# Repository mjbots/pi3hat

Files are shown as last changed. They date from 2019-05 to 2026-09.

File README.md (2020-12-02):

# mjbots pi3hat #

This contains designs, firmware, and client side libraries for the
mjbots pi3hat.  It is a daughterboard for Raspberry Pi (tm) boards and
similar to provide:

* 4x 5Mbps CAN-FD ports
* 1x 125kbps CAN port
* 1kHz IMU with attitude reference

# LICENSE #

All files contained in this repository, unless otherwise noted, are
available under an Apache 2.0 License
https://www.apache.org/licenses/LICENSE-2.0

# Directory Structure #

* hw/ - Eagle schematic
* fw/ - Firmware
* docs/ - Reference documentation
* lib/ - Client side libraries
* tools/ - bazel build configuration

# FAQ #

## How do I get the best timing performance? ##

A: We recommend using the following configuration:
 * `isolcpus` and `sched_setaffinity` used to keep linux from running
   on the processor interfacing with the pi3hat
 * `chrt 99` to run the process at the maximum real time priority
 * `mlockall` to prevent linux from swapping any part of the process

These are demonstrated in the `--realtime` option of `pi3hat_tool`.

## Will this work on a Raspberry Pi 4? ##

A: Despite the name `pi3hat`, yes it works just fine on a Raspberry Pi
4 too.

## Do I need to use the XT 30 input connector? ##

A: Nope.  You can power the Raspberry Pi with through any means.  The
pi3hat internally only uses the 3.3V output from the Raspberry Pi, and
the input connector is just an independent mechanism to power the Pi.

## Will this work on **insert random board here**? ##

A: Maybe?  If it has the same pinout as a Raspberry Pi, can can be
powered through the GPIO header with 5V @ 2.5A then there is a chance.

## Can I use the Raspberry Pi Camera? ##

A: If you install a higher GPIO riser then it is possible.  Samtec
ESW-120-12-G-D works.  You can install one yourself, or contact
info@mjbots.com to get one fitted at the factory.

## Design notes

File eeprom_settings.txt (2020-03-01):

########################################################################
# EEPROM settings text file
#
# Edit this file for your particular board and run through eepmake tool,
# then use eepflash tool to write to attached HAT ID EEPROM 
#
# Tools available:
#  eepmake   Parses EEPROM text file and creates binary .eep file
#  eepdump   Dumps a binary .eep file as human readable text (for debug)
#  eepflash  Write or read .eep binary image to/from HAT EEPROM
#
########################################################################

########################################################################
# Vendor info

# 128 bit UUID. If left at zero eepmake tool will auto-generate
# RFC 4122 compliant UUID
product_uuid 00000000-0000-0000-0000-000000000000

# 16 bit product id
product_id 0x2306

# 16 bit product version
product_ver 0x0001

# ASCII vendor string  (max 255 characters)
vendor "mjbots Robotic Systems"

# ASCII product string (max 255 characters)
product "mjbots quad pi3 hat"

########################################################################
# GPIO bank settings, set to nonzero to change from the default.
# NOTE these setting can only be set per BANK, uncommenting any of
# these will force the bank to use the custom setting.

# drive strength, 0=default, 1-8=2,4,6,8,10,12,14,16mA, 9-15=reserved
gpio_drive 0

# 0=default, 1=slew rate limiting, 2=no slew limiting, 3=reserved
gpio_slew 0

# 0=default, 1=hysteresis disabled, 2=hysteresis enabled, 3=reserved
gpio_hysteresis 0

# If board back-powers Pi via 5V GPIO header pins:
# 0 = board does not back-power
# 1 = board back-powers and can supply the Pi with a minimum of 1.3A
# 2 = board back-powers and can supply the Pi with a minimum of 2A
# 3 = reserved
# If back_power=2 then USB high current mode will be automatically 
# enabled on the Pi
back_power 2

########################################################################
# GPIO pins, uncomment for GPIOs used on board
# Options for FUNCTION: INPUT, OUTPUT, ALT0-ALT5
# Options for PULL: DEFAULT, UP, DOWN, NONE
# NB GPIO0 and GPIO1 are reserved for ID EEPROM so cannot be set

#         GPIO  FUNCTION  PULL
#         ----  --------  ----
#setgpio  2     INPUT     DEFAULT
#setgpio  3     INPUT     DEFAULT
#setgpio  4     INPUT     DEFAULT
#setgpio  5     INPUT     DEFAULT
#setgpio  6     INPUT     DEFAULT
# SPI0 is 7-11 on ALT0
setgpio  7     ALT0     NONE
setgpio  8     ALT0     NONE
setgpio  9     ALT0     NONE
setgpio  10    ALT0     NONE
setgpio  11    ALT0     NONE
#setgpio  12    INPUT     DEFAULT
#setgpio  13    INPUT     DEFAULT
# 14-15 are UART0 on ALT0
setgpio  14    ALT0     NONE
setgpio  15    ALT0     NONE
# SPI1 is 16-21 on ALT4
setgpio  16    ALT4     NONE
setgpio  17    ALT4     NONE
setgpio  18    ALT4     NONE
setgpio  19    ALT4     NONE
setgpio  20    ALT4     NONE
setgpio  21    ALT4     NONE
#setgpio  22    INPUT     DEFAULT
#setgpio  23    INPUT     DEFAULT
#setgpio  24    INPUT     DEFAULT
#setgpio  25    INPUT     DEFAULT
#setgpio  26    INPUT     DEFAULT
#setgpio  27    INPUT     DEFAULT

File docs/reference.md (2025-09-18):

# mjbots pi3 hat #

This is the reference documentation for the mjbots pi3hat r4.5.
What is it?

The mjbots pi3hat is a daughterboard for a Raspberry Pi (tm) 3 or
Raspberry Pi 4 [1], which provides the following:

 * Power input from 8-54V [2], provides 5V for Raspberry Pi
 * 5x independent 5Mbps CAN-FD buses
 * A 1kHz IMU and attitude reference system
 * A spread spectrum nrf24l01 interface

1. The pi3hat is not compatible with the Raspberry Pi 1, 2, or 5.
2. The pi3hat r4.4 and earlier support 8-44V DC input.

# Pinouts #

## J1/J2 ##

XT30-M power input/output.  The chamfered side of the connector is
negative.

## JC1/JC2/JC3/JC4/JC5 ##

These are JST PH-3, 5Mbps CAN-FD connectors.  Each has a physical
termination resistor permanently installed.

* Pin 1: CANH
* Pin 2: CANL
* Pin 3: Ground

# Orientation #

The pi3hat uses a right handed coordinate system.  The raw IMU
accelerations and rotations are measured about the following axes:

* +x - towards the CAN connectors or HDMI connectors on the RPI
* +y - towards the USB ports on the rpi
* +z - up from the rpi towards the pi3hat

Attitude is measured with respect to a coordinate system of:
* +x forward
* +y right
* +z down

That means, in the absence of any configured mounting angle, the
raspberry pi must be inverted to achieve a pitch and roll of 0.

Finally, note that pi3hat is only an "attitude reference system", and
contains no sensors for measuring heading.  Thus the yaw or heading
value will drift over time and the yaw rate will have a non-zero bias
offset.

# Usage with client-side tools #

## tview / moteus_tool ##

First, install the python library:

```
python -m venv --system-site-packages moteus-venv
source moteus-venv/bin/activate

pip3 install moteus moteus-pi3hat
```

Then both `moteus_tool` and `tview` will be aware of the pi3hat, and
will use its port JC1 by default if no fdcanusb is present.

To use other ports, you need to tell the tool which IDs are present on
which port using the `--pi3hat-cfg` command line option.  It has the
following syntax:

```
--pi3hat-cfg 'BUS1=ID1,ID2,ID3;BUS2=ID4,ID5,ID6
```

So, an example where servo ID 1 and 6 are present on port JC1 (bus 1),
and 3 and 7 are present on port JC2 (bus 2), would look like:

```
sudo bash
source moteus-venv/bin/activate

tview --pi3hat-cfg '1=1,6;2=3,7' -t 1,3,6,7
```

The same `--pi3hat-cfg` works for `moteus_tool` as for `tview`.

## Python ##

Simply perform:

```
sudo apt install libraspberrypi-dev

# If not already created
# python -m venv --system-site-packages moteus-venv

source moteus-venv/bin/activate
pip3 install moteus-pi3hat
```

Then use the same API documented at:
https://github.com/mjbots/moteus/tree/main/lib/python with the caveat that all scripts must be executed as root.

Alternately, the pi3hat transport can be constructed directly using:

```
import moteus
import moteus_pi3hat

transport = moteus_pi3hat.Pi3HatRouter(
    servo_bus_map={...},
)
controller = moteus.Controller(id=1, transport=transport)
```

## C++ ##

To use the pi3hat with C++, a library is provided at:
 https://github.com/mjbots/pi3hat/blob/master/lib/cpp/mjbots/pi3hat/pi3hat.h

It consists of a single standalone C++11 header and source file, which
depends upon nothing but the standard library.  The library provides a
blocking interface that allows all the ports and features to be used
in an efficient manner.  Internally, it bypasses the linux kernel
drivers (which requires it to be run as root), and sometimes
busy-waits the CPU, in order to achieve tight timing performance.

There is a sample user of this library, `pi3hat_tool` in the same
directory which provides a simple command line program that exercises
all of its functionality.

## Board level documentation ##

If you wish to use the existing linux kernel SPI drivers, or write a
custom driver, the board theory of operation and SPI register mappings
are described here.

Internally, the board has 3 separate STM32 processors, each attached
to a SPI bus on the Raspberry Pi:

* *Processor 1* The first processor provides the high speed CAN-FD
  interfaces for CAN connectors JC1 and JC2.  It is connected to the
  Raspberry Pi SPI1 bus, CS0.  Those are the following pins on the 40
  pin GPIO header:

  * Pin 35: CIPO (BCM 19)
  * Pin 38: COPI (BCM 20)
  * Pin 40: SCLK (BCM 21)
  * Pin 12: CS   (BCM 18)
  * Pin 37: IRQ  (BCM 26)

* *Processor 2*: This processor provides the CAN-FD interfaces for JC3
  and JC4.  It is connected to the Raspberry Pi SPI1 bus, CS1.  Pins:

  * Pin 35: CIPO (BCM 19)
  * Pin 38: COPI (BCM 20)
  * Pin 40: SCLK (BCM 21)
  * Pin 11: CS   (BCM 17)
  * Pin 29: IRQ  (BCM 5)

* *Processor 3*: This processor provides the low-speed CAN interface,
  the IMU, and the nrf24l01 logic.  It is connected to the Raspberry
  Pi SPI0 bus, CS0.

  * Pin 21: CIPO (BCM 9)
  * Pin 19: COPI (BCM 10)
  * Pin 23: SCLK (BCM 11)
  * Pin 24: CS   (BCM 8)
  * Pin 15: IRQ  (BCM 22)
  * Pin 16: IRQ  (BCM 23)
  * Pin 18: IRQ  (BCM 24)

# Debugging connectors #

## JP6 ##

 * 1: 5V
 * 2: 3.3V
 * 3: Ground

## I2C ##

This connector directly breaks out I2C pins from the Raspberry Pi:

 * 1: 3.3V
 * 2: SDA / RPI Pin 3
 * 3: SCL / RPI Pin 5
 * 4: Ground

## UT ##

This connector directly breaks out UART pins from the Raspberry Pi:

 * 1: TX / RPI 32
 * 2: RX / RPI 33
 * 3: Ground

## JP4 ##

Reserved debugging connector for processor 1.

## JP3 ##

Reserved debugging connector for processor 2

## JP2 ##

Reserved debugging connector for processor 3

# SPI Protocol #

All of the processors use the same basic SPI protocol, with unique
registers for each of the various functions.

Maximum frequency: 10MHz

The following sequence is used for all SPI transactions (write or
read).

1. CS is pulled low
2. A >= 3 us hold time
3. An 8 byte address is written MSB first
4. A >= 3 us hold time
5. One or more bytes can now be read or written.  When reading, 0's
   should be clocked out.  When writing, the return value can be
   ignored.  Each "address" logically consists of sequence of bytes.
6. A >= 3 us hold time
7. CS is pulled high
8. A minimum 3us turnaround time is required before CS can be pulled
   low again.

## CAN Register Mapping ##

These addresses are present on processor 1, 2, and 3.

* *0* Protocol version: A constant byte 0x04
* *1* Interface type: A constant byte 0x01
* *2* Receive status
  * byte 0-5: Size of up to 6 received frames.  0 means no frame is
    available.  This size includes header information, so is the total
    number of bytes that must be read from address 3 to get a complete
    frame.
* *3* Received frame
  * Reading this address consumes exactly one frame from the received
    queue.
  * byte 0: (0x00 means no data)
    * bit 7: which port this was received on 0=JC1/JC3/JC5 1=JC2/JC4
    * bit 6-0: size of payload + 1 (1-65)
  * byte 1-4: CAN ID, MSB first
  * byte 5+: payload
* *4* Transmit frame with 4 byte ID
  * Writing to this address enqueues one CAN frame to be sent.
  * byte 0:
    * bit 7: which port to send on 0=JC1/JC3/JC5 1=JC2/JC4
    * bit 6-0: size of payload
  * byte 1-4: CAN ID, MSB first
  * byte 5+: payload
* *5* Transmit frame with 2 byte ID
  * Writing to this address enqueues one CAN frame to be sent.
  * byte 0:
    * bit 7: which port to send to 0=JC1/JC3/JC5 1=JC2/JC4
    * bit 6-0: size of payload
  * byte 1-2: CAN ID, MSB first
  * byte 3+: payload
* *6* Error status (read only)
  * Port 0 (JC1/JC3/JC5)
    * byte 0
      * bit 7-6 activity
      * bit 5-3 data last error code
      * bit 2-0 last error code
    * byte 1
      * bit 3 protocol exception
      * bit 2 bus_off
      * bit 1 warning status
      * bit 0 error passive
    * byte 2 - rx error count
    * byte 3 - tx error count
    * byte 4 - reset count
    * byte 5 - reserved
  * Port 1 (JC2/JC4)
    * byte 6
      * bit 7-6 activity
      * bit 5-3 data last error code
      * bit 2-0 last error code
    * byte 7
      * bit 3 protocol exception
      * bit 2 bus_off
      * bit 1 warning status
      * bit 0 error passive
    * byte 8 - rx error count
    * byte 9 - tx error count
    * byte 10 - reset count
    * byte 11 - reserved
* *7* Read configuration Port 1 (JC1/JC3/JC5)
  * byte 0-3: int32 standard bitrate
  * byte 4-7: int32 CAN-FD bitrate
  * byte 8: generate CAN-FD frames
  * byte 9: switch bitrates
  * byte 10: enable automatic retransmission
  * byte 11: restricted mode
  * byte 12: bus monitor mode
  * byte 13: std prescaler
  * byte 14: std sync_jump_width
  * byte 15: std time_seg1
  * byte 16: std time_seg2
  * byte 17: std prescaler
  * byte 18: std sync_jump_width
  * byte 19: std time_seg1
  * byte 20: std time_seg2
* *8* Read configuration Port 2 (JC2/JC4)
  * Same as for 7
* *9* Write configuration Port 1 (JC1/JC3/JC5)
  * Same as for 7
* *10* Write configuration Port 2 (JC2/JC4)
  * Same as for 7

## IMU Register Mapping ##

These addresses are present only on processor 3.

* *32* Protocol version: A constant byte 0x20
* *33* Raw IMU data
  * uint16 _present_
  * float _gx dps_
  * float _gy dps_
  * float _gz dps_
  * float _ax mps2_
  * float _ay mps2_
  * float _az mps2_
* *34* Attitude Data
  * uint8 _present_
  * uint8 _reserved_
  * float _w_
  * float _x_
  * float _y_
  * float _z_
  * float _x dps_
  * float _y dps_
  * float _z dps_
  * float _ax mps2_
  * float _ay mps2_
  * float _az mps2_
  * float _bias x dps_
  * float _bias y dps_
  * float _bias z dps_
  * float _uncertainty w_
  * float _uncertainty x_
  * float _uncertainty y_
  * float _uncertainty z_
  * float _uncertainty bias x dps_
  * float _uncertainty bias y dps_
  * float _uncertainty bias z dps_
  * uint32 _error count_
  * uint32 _last error_
* *35* Read configuration
  * float _roll deg_
  * float _pitch deg_
  * float _yaw deg_
  * uint32t _rate Hz_
* *36* Write configuration
  * The same structure as for address 35.

## RF Register Mapping ##

If a nrf24l01 module is attached, the pi3hat implements a spread
spectrum receiver.  This receiver must be configured with the same ID
as the transmitter for communication to take place.

Each "slot" is transmitted independently and repeatedly according to
the given bitmask schedule.  The individual RF frames occur at 50Hz,
and each bit in the bitmask controls whether the data should be sent
in that particular frame.  So 0xaaaaaaaa would result in the data
being sent every other frame.

* *48* Protocol version: A constant byte 0x11
* *49* Read ID
  * byte 0-3: Common RF ID
* *50* Write ID
* *51* Set data for transmission
  * byte 0: Slot number (0-15)
  * byte 1-4: Transmission schedule (little endian)
  * byte 5+: Data
* *52* Read status
  * byte 0-3: uint32 rx slot counter, 2 bits per slot (little endian)
    * each time new data is received from the transmitter, the 2 bit
      counter for that slot is incremented
  * byte 4-7: uint32 age since last lock from tx (little endian)
* *64-79* Read data from remote transmitter
  * byte 0-3: uint32 age in ms (little endian)
  * byte 4: size (0-16)
  * byte 5-20: data

# Flashing new firmware #

To flash new firmware, openocd 0.11.0 or newer is required.  You can find binaries for many platforms at: https://xpack.github.io/openocd/releases/

Flashing can be performed using the `flash.py` script, for instance to flash a newly compiled image:

```
./flash.py
```

Or to flash a specific .elf file

```
./flash.py 20211129-pi3hat-71c002e71ce804959e681dc7043f6fb5d8147cac.elf
```

Each of the three processors needs to be flashed with the same image.

# pi3hat_tool #

Compiled versions of pi3hat_tool can be found in each github release: https://github.com/mjbots/pi3hat/releases

You want the YYYYMMDD-pi3hat_tools-*.bz2, selecting the appropriate
file for your architecture.

pi3hat_tool can be used perform various diagnostic functions,
including reading attitude:

```
pi@realtimepi:~ $  sudo bash

root@raspberrypi:/home/pi# ./pi3hat_tools/pi3hat_tool --read-att
```

Which will then display the current attitude information.

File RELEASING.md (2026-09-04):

# Releasing pi3hat

pi3hat ships three artifacts that move together under a **single
version** and a **single `vX.Y.Z` tag**:

| Artifact | What it is |
|---|---|
| firmware | the flashable STM32G4 image (`pi3_hat.elf` / `.bin`) |
| python | the `moteus_pi3hat` wheels (one per Python version × Pi architecture) |
| cpp | the header/`FetchContent` C++ client source archive |

A single GitHub Release for the tag carries all of them. The version
lives in two files, kept in sync by `utils/release.py`:

| File | Field | Form |
|---|---|---|
| `lib/python/BUILD` | `VERSION="X.Y.Z"` | full PEP 440 (`1.0.0rc1`) |
| `CMakeLists.txt` | `project(... VERSION X.Y.Z)` | `M.m.p` only (no suffix) |

The Python package is published to PyPI, so the version string must be a
normalized [PEP 440](https://peps.python.org/pep-0440/) version
(`1.0.0`, `1.0.0rc1`, `1.0.0b1`, `1.0.0.dev1`) — *not* the semver
spelling `1.0.0-rc.1`. CMake's `project(VERSION)` only accepts `M.m.p`,
so any pre-release suffix is dropped from `CMakeLists.txt` while the full
string is kept for the wheel and the tag.

## Cutting a release

Run the helper from the repo root, then push:

```bash
# patch bump (1.0.0 -> 1.0.1)
utils/release.py patch

# minor / major
utils/release.py minor
utils/release.py major

# start a pre-release cycle (explicit)
utils/release.py 1.1.0rc1

# iterate a pre-release (1.1.0rc1 -> 1.1.0rc2)
utils/release.py rc

# graduate a pre-release to its final release (1.1.0rc2 -> 1.1.0)
utils/release.py patch

# also bump the Rust crate (on its own pre-stable 0.x line)
utils/release.py patch --rust patch
```

The `patch` bump is overloaded: when current is already a pre-release it
strips the suffix instead of incrementing the patch number (matches
npm/cargo conventions). `minor` and `major` always advance `M.m.p`.

The Rust crate (`lib/rust/moteus-pi3hat`) is versioned separately while
it is pre-stable: it stays on its own `0.x` line rather than the unified
`1.x` number, and is bumped — and later published to crates.io — only
when you pass `--rust`. Omit `--rust` and the crate version is left
untouched, so a release that does not change the crate does not
republish it. `--rust` takes the same `major`/`minor`/`patch` bumps or
an explicit semver version (e.g. `--rust 0.2.0`). When the crate is
declared stable, bump it onto the unified number once with `--rust <that
version>` and pass `--rust` on every release thereafter.

The script:

1. Reads the current version from `lib/python/BUILD`.
2. Computes the new version (or accepts an explicit one) and validates it
   is normalized PEP 440.
3. Writes the new version to `lib/python/BUILD` and `CMakeLists.txt`
   (and, with `--rust`, the crate version to `lib/rust/Cargo.toml`).
4. Commits (if a file changed) and creates the annotated tag `vX.Y.Z`.
5. Prints the `git push` commands.

Before any of that it checks that `CHANGELOG.md` has a `## X.Y.Z`
section with entries for the new version and refuses to tag otherwise
-- rename `## Unreleased` first.  (Entries themselves are added with
the change that introduces them, not at release time.)

Inspect the diff and tag before pushing.

```bash
git push origin HEAD
git push origin v1.0.1
```

You can also kick off a release from the GitHub UI via the
[`Release`](.github/workflows/release.yml) workflow — it runs the same
script in CI, useful when releasing from somewhere without your local
toolchain.

## What the build produces

Pushing the tag fires
[`build-release.yml`](.github/workflows/build-release.yml), which builds
on `ubuntu-24.04` and attaches all of the following to one **draft**
GitHub Release:

- **Firmware**: `pi3hat-fw-<version>+g<sha>.elf` and `.bin`, built with
  `tools/bazel build --cpu stm32g4 -c opt //:target`. The `+g<sha>`
  portion is semver build metadata (the 10-char git short SHA of the
  tagged commit), ignored for version precedence.
- **Python**: for each Python version (3.7, 3.9–3.13) × Pi architecture
  (`armv7l`, `aarch64`), it cross-compiles `//:pi3hat_tools` and attaches
  both:
  - `moteus_pi3hat-<version>-cp<py>-<abi>-<plat>.whl` — the wheel that
    goes to PyPI.
  - `pi3hat_tools-<version>-cp<py>-<arch>.tar.bz2` — the full tool
    bundle (the `pi3hat_tool` binary, the wheel, and the C++ examples +
    sources).
- **C++**: `pi3hat-cpp-<version>.tar.gz`, a source archive of the
  `FetchContent` C++ client (`CMakeLists.txt`, `LICENSE`,
  `lib/cpp/mjbots/pi3hat`, `lib/cpp/examples`). The C++ client is
  normally consumed via `FetchContent` pointing at the `vX.Y.Z` tag;
  this archive is just a convenience download.

The build refuses to run if the pushed tag's version disagrees with
`VERSION` in `lib/python/BUILD` (the wheel filenames are derived from
that file). `utils/release.py` keeps them in sync, so this only trips on
a hand-made tag.

Drafts are not visible to users browsing the Releases page or to `pip`
consumers — they exist only on the maintainer's view of the page.

## Promoting a draft release to public

After the build workflow finishes, validate the draft locally:

1. Go to the repo's Releases page → the draft shows under "Draft" at the
   top. Download the attached artifacts.
2. Flash the firmware on representative hardware; `pip install` a wheel
   into a fresh venv on a Pi and exercise `moteus_tool`/`pi3hat_tool`.
3. When satisfied, publish — click "Publish release" in the UI, or:

   ```bash
   gh release edit v1.0.0 --draft=false
   ```

If something is wrong, abort instead of publishing:

```bash
gh release delete v1.0.0 --yes
git push --delete origin v1.0.0
git tag -d v1.0.0
# ...fix the issue, then re-tag
```

**Promoting the draft is what triggers the PyPI publish.**
[`publish-python-pypi.yml`](.github/workflows/publish-python-pypi.yml)
listens for the `release: published` event, downloads the `*.whl` assets,
and uploads them to PyPI via OIDC. Do not publish a draft until you
intend the wheels to land on PyPI — PyPI is append-only, you cannot
un-publish (only yank).

A pre-release version (anything PEP 440 considers pre-release, e.g.
`1.0.0rc1`) goes to PyPI but `pip install moteus_pi3hat` won't pick it up
unless the user passes `--pre`. So pre-releases are safe to publish.

## Publishing to PyPI — one-time setup

PyPI publishing uses
[trusted publishing](https://docs.pypi.org/trusted-publishers/) via OIDC,
so no API token is stored in this repo.

1. Sign in to PyPI as a maintainer of the `moteus_pi3hat` project.
2. Project settings → Publishing → Add a new pending publisher (or
   trusted publisher if the project already exists). Configure:
   - Owner: `mjbots`
   - Repository name: `pi3hat`
   - Workflow name: `publish-python-pypi.yml`
   - Environment name: `pypi`
3. In this GitHub repo: Settings → Environments → New environment named
   `pypi`. The environment exists so PyPI's trusted-publishing config has
   something to bind to; no required reviewers are needed because the
   "Publish release" action on the draft is the gate.

## Publishing to crates.io — one-time setup

The Rust crate publishes the same way, via crates.io
[trusted publishing](https://crates.io/docs/trusted-publishing) over
OIDC, so no token is stored in the repo.

crates.io trusted publishing is configured under an existing crate's
settings, so the crate must exist first. For the initial `0.x` publish,
run `cargo publish` once manually with a personal API token to create
the crate; then:

1. Sign in to crates.io as an owner of the `moteus-pi3hat` crate.
2. Crate settings → Trusted Publishing → Add a GitHub publisher:
   - Owner: `mjbots`
   - Repository name: `pi3hat`
   - Workflow filename: `publish-rust-crates.yml`
   - Environment name: `crates-io`
3. In this GitHub repo: Settings → Environments → New environment named
   `crates-io` (same role as `pypi`).

Prefer a stored token instead of OIDC? Drop the auth step in
`publish-rust-crates.yml` and add a `CARGO_REGISTRY_TOKEN` secret to the
`crates-io` environment.

## What each workflow does

- [`release.yml`](.github/workflows/release.yml) — manual
  `workflow_dispatch` to bump the version and tag from CI.
- [`build-release.yml`](.github/workflows/build-release.yml) — fires on a
  `v*` tag. Builds the firmware, the cross-compiled Python wheels + tool
  bundles, and the C++ source archive, and attaches them all to one draft
  Release.
- [`publish-python-pypi.yml`](.github/workflows/publish-python-pypi.yml)
  — fires when a `v*` Release is promoted out of draft. Downloads the
  attached wheels and uploads them to PyPI via OIDC trusted publishing.
- [`publish-rust-crates.yml`](.github/workflows/publish-rust-crates.yml)
  — fires when a `v*` Release is promoted out of draft. Builds the
  tagged `moteus-pi3hat` crate and publishes it to crates.io via OIDC
  trusted publishing, skipping if that version is already published.
- [`ci.yml`](.github/workflows/ci.yml) — runs `travis-ci.sh` on every
  push and pull request.

## Local builds

`make_release.py` still builds the same artifacts locally into an output
directory (naming them by date + git hash rather than by version). It is
handy for ad-hoc builds, but the tag-driven `build-release.yml` is the
canonical release path.

## Rust dependency lockfiles

`lib/rust` carries two committed lockfiles: `Cargo.lock` (cargo's own)
and `Cargo.bazel.lock` (the rules_rust crate_universe resolution built
from it). After changing any dependency specification (a crate's
`Cargo.toml`, or the crate list in `WORKSPACE`), regenerate both:

```bash
cd lib/rust && cargo update --workspace   # refreshes Cargo.lock minimally
CARGO_BAZEL_REPIN=1 ./tools/bazel sync --only=crate_index
```

A stale `Cargo.bazel.lock` fails the bazel build with a message that
names `CARGO_BAZEL_REPIN`, so drift is caught rather than silent.

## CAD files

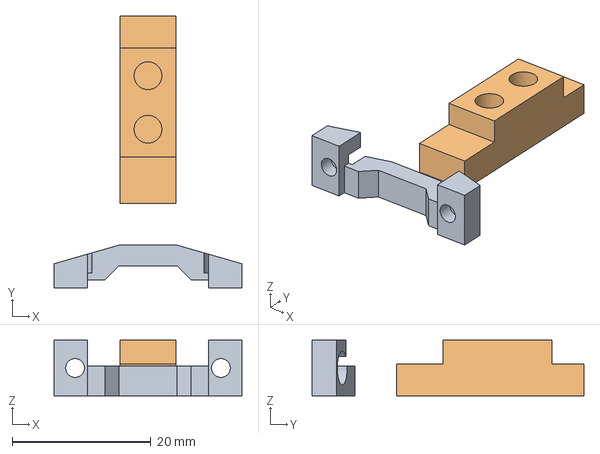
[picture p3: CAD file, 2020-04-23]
3dprint/pi3hat_20200422/rf_clamp.3mf
27.0 x 39.2 x 8.00 mm
rf_clamp.stl
rf_support.stl

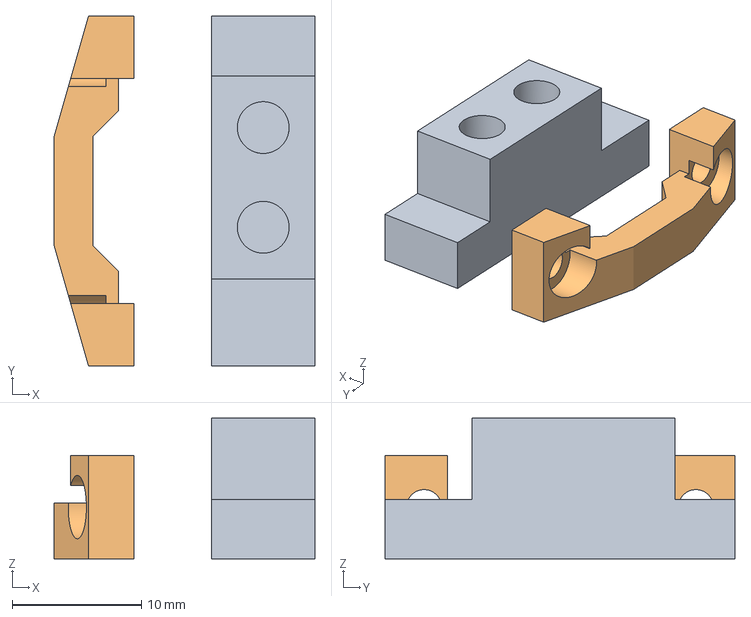
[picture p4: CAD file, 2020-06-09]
3dprint/pi3hat_20200423/rf_support_and_clamp.3mf
20.2 x 27.0 x 10.9 mm
rf_support.stl
rf_clamp.stl

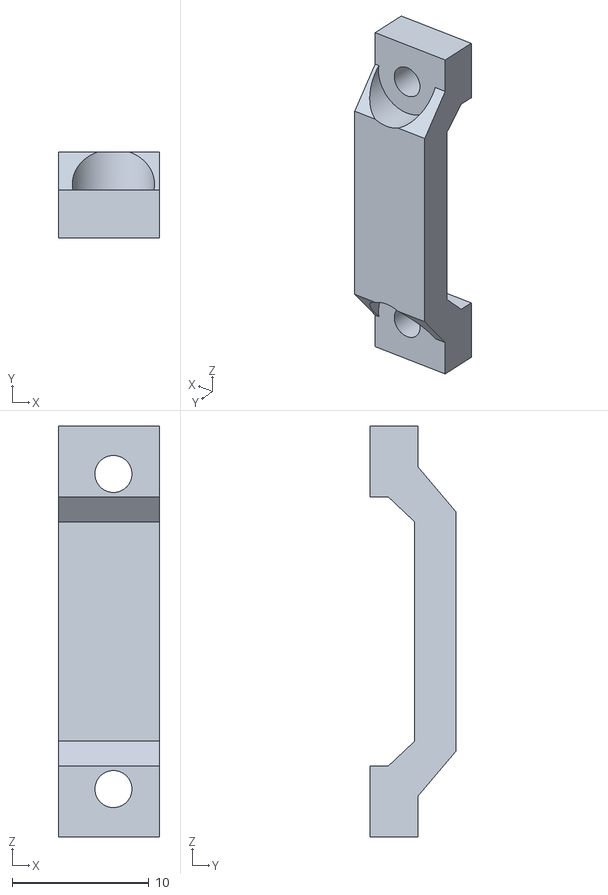
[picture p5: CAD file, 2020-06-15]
3dprint/pi3hat_20200614/rf_clamp.stl
7.35 x 6.25 x 30.0

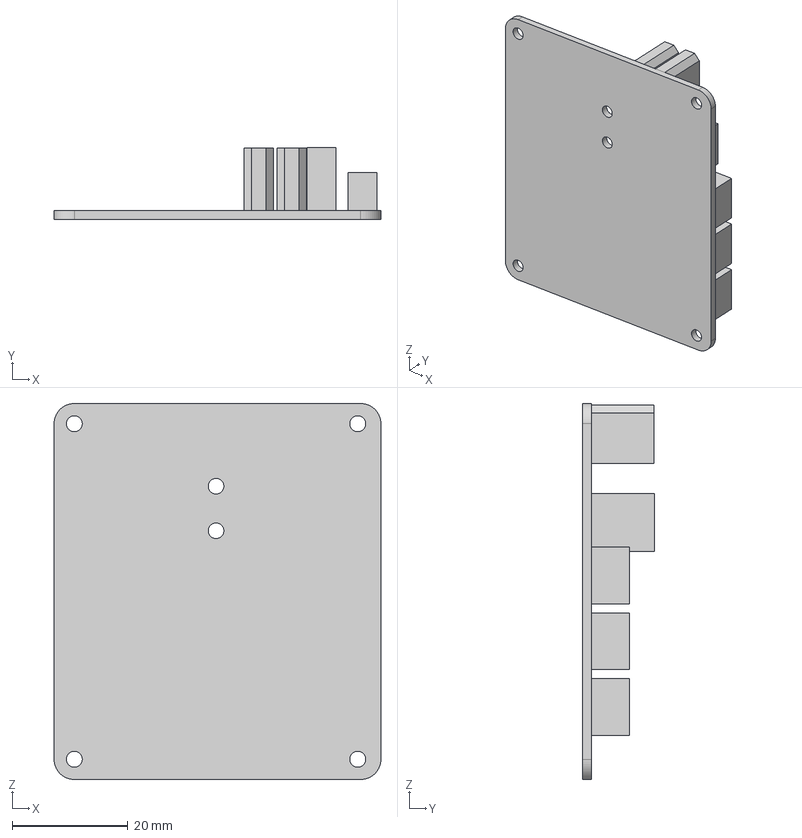
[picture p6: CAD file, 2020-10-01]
hw/r4.1/pi3hat_r4_1.step
56.5 x 12.4 x 65.0 mm

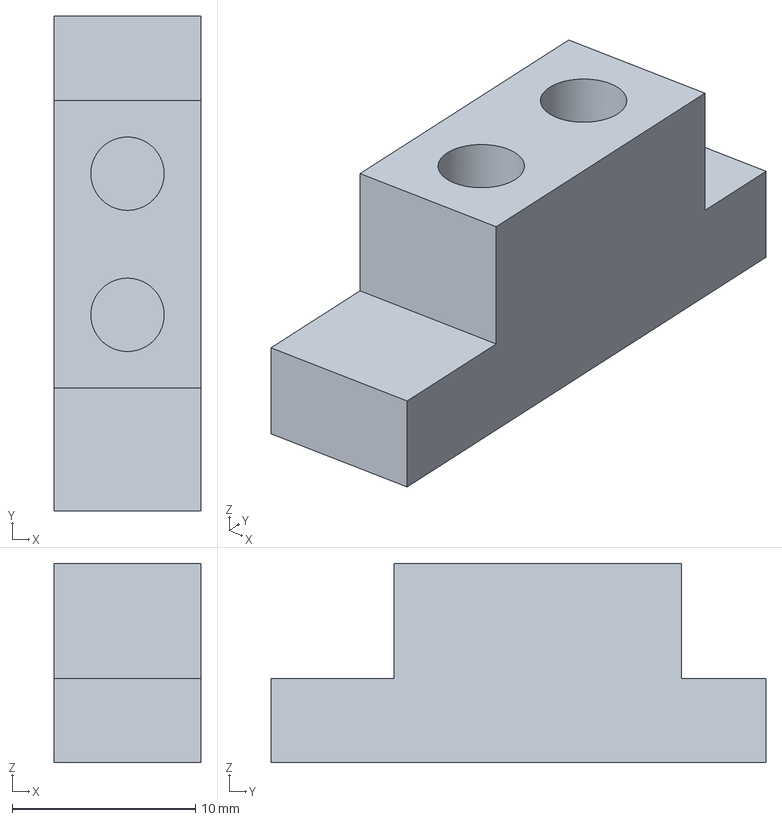
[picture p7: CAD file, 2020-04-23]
3dprint/pi3hat_20200423/rf_support.3mf
8.00 x 27.0 x 10.9 mm

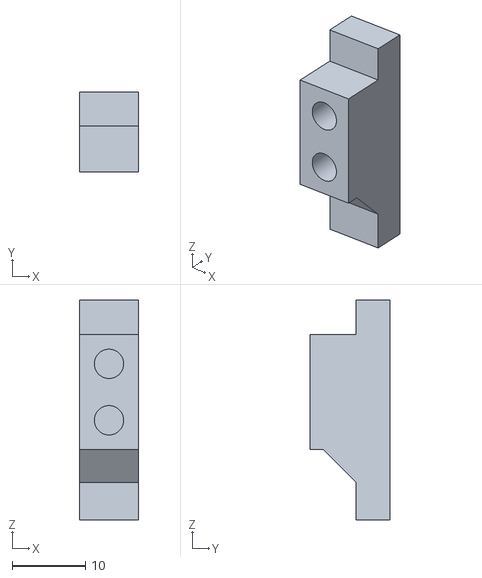
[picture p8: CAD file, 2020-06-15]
3dprint/pi3hat_20200614/rf_support.stl
8.00 x 10.9 x 30.0

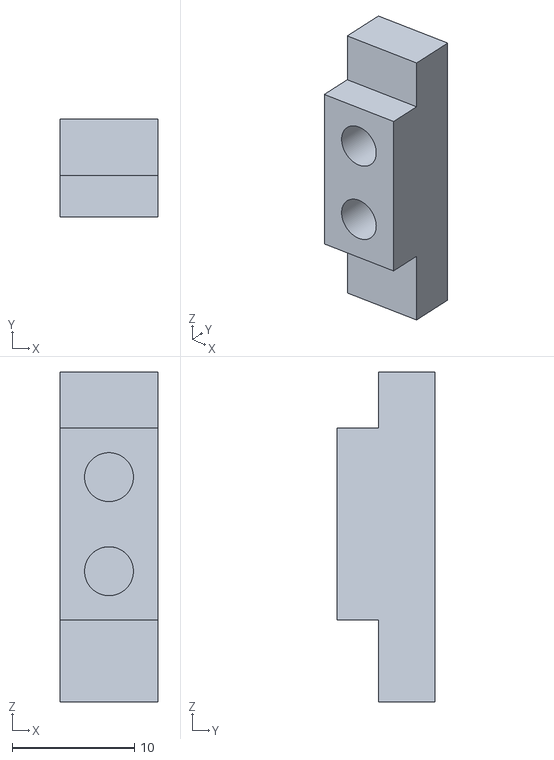
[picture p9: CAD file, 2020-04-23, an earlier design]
3dprint/pi3hat_20200422/rf_support.stl
8.00 x 8.00 x 27.0

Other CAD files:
3dprint/pi3hat_20200422/rf_clamp.stl
3dprint/pi3hat_20200423/rf_support.stl

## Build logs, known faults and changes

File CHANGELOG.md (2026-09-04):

# Changelog

pi3hat ships firmware, the `moteus_pi3hat` Python client, and the C++
client together under a single version; see [RELEASING.md](RELEASING.md)
for the process.

The format is loosely based on [Keep a Changelog](https://keepachangelog.com/).

Entries are added under `## Unreleased` by the change that introduces
them; cutting a release only renames that heading to the version and
date.

## Unreleased

- New Rust client library and moteus transport, `moteus-pi3hat`
  (`lib/rust`), a direct translation of the C++ library. It is
  published to crates.io from the release workflow on its own `0.x`
  version line (`utils/release.py --rust`); the first release is
  0.1.0.
- The tools bundle also ships the Rust examples under `examples/rust/`
- `--pi3hat-cpu` (C++ and Rust) now defaults to the highest isolated
  CPU when the system has any (`isolcpus`), pinning the SPI worker
  there at realtime priority; previously the worker stayed unpinned
  unless a CPU was given. Pass `-1` to never pin.
- C++: `--pi3hat-cfg` rejects out-of-range buses and a servo id mapped
  to more than one bus instead of silently misrouting.
- C++: guard against malformed short CAN frames in `ReadCanFrames`
- C++: fix a race on `Pi3HatMoteusTransport` construction where the
  worker thread could start before its members were constructed
  (intermittent segfault).
- C++: document that `CanConfiguration::restricted_mode` is ignored.
- Documentation: the JC1-4 high speed vs JC5 low speed distinction
  only applied to boards older than r4.5; modern boards make none.
- CI also compiles the Rust crate in its published configuration
  (crates.io `moteus`, locked) and on its declared MSRV (1.75).

## 1.0.0

- First unified semver release. Firmware, the `moteus_pi3hat` Python
  package, and the C++ client now share one version and one `vX.Y.Z` tag.
- Release engineering: tag-driven GitHub Actions build all three
  artifacts into a single Release; promoting the Release publishes the
  Python wheels to PyPI via OIDC trusted publishing.
- The Python package now depends on `moteus>=1.0.0rc1`.

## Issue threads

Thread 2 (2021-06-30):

Max input voltage

Sherdycoder, 2021-06-30:
Reference.md states that the pihat accepts power input from 8-34V, but the product description states 8-44V.

jpieper, 2021-06-30:
Fixed in https://github.com/mjbots/pi3hat/commit/252493835b6ae4a8fa95bc4b884819cf9e681f73

(those specs were for an older version)

Closed 2021-06-30.

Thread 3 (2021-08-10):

moteus_tool auto-detection does not work well on the pi3hat

jpieper, 2021-08-10:
It almost always reports target 1 as available, and then wedges, requiring a power cycle.

Observed in 2021-08-10

jpieper, 2021-08-10:
Resolved in https://github.com/mjbots/moteus/commit/fa707be362e85571b9e7efd7258763730c8dcef3

Closed 2021-08-10.

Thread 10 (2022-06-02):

pi3hat communication is unreliable with 64 bit Raspberry Pi OS

jpieper, 2022-06-02:
Observed by @stephane-caron

When a 64 Raspberry Pi OS is used, flashing moteus controllers over the pi3hat's CAN-FD ports often fails.

jpieper, 2022-06-16:
I've narrowed down the problem to BusyWaitUs not waiting long enough on the 64 bit Pi OS, which can result in the address setup time being violated.  I'm guessing the time resolution is worse, so that subsequent polls can show a larger jump than actually occurred.

I'll have to do some research to see if there is any finer source of timing available.

jpieper, 2022-06-16:
Resolved in d4755d7e01b29cb16e875d17da1546233ea8b6ae and released on pypi as 0.3.21

Closed 2022-06-16.

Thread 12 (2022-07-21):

pi3hat-tool Missing from Pip

MiNdLiKeAsPoOn, 2022-07-21:
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

jpieper, 2022-07-21:
`moteus-pi3hat` can only be installed on a Raspberry Pi running Raspberry Pi OS and some versions of Ubuntu.

`pi3hat_tool` is also not in the pip package, but is available in the separate "tools" package, which is available on the github release page.  It also only runs on the Rasbperry Pi on Linux.

MiNdLiKeAsPoOn, 2022-07-21:
Understood. Thanks and apologies for the mistake

Closed 2022-07-21.

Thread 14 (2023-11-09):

Some issues regarding communication with PI3hat boards

MaxKingWealth, 2023-11-09:
**Hi author, I am trying to use orangepi or upboard to communicate with pi3hat, after installing moteus-pi3hat, my sample code is as follows,**
import asyncio
import math
import moteus
import moteus_pi3hat
import time

async def main():
    transport = moteus_pi3hat.Pi3HatRouter(
        servo_bus_map={
            1:[11]
            },
    )
    controller = moteus.Controller(id=1, transport=transport)

**and after running it, the following error occurs， I would like to ask if there is something wrong with my operation？**

sudo python demo.py
Traceback (most recent call last):
  File "/home/orangepi/Desktop/pi3hat/demo.py", line 96, in <module>
    asyncio.run(main())
  File "/usr/lib/python3.10/asyncio/runners.py", line 44, in run
    return loop.run_until_complete(main)
  File "/usr/lib/python3.10/asyncio/base_events.py", line 646, in run_until_complete
    return future.result()
  File "/home/orangepi/Desktop/pi3hat/demo.py", line 11, in main
    transport = moteus_pi3hat.Pi3HatRouter(
  File "/usr/local/lib/python3.10/dist-packages/moteus_pi3hat/pi3hat_router.py", line 108, in __init__
    self._impl = _pi3hat_router.Pi3HatRouter(options)
RuntimeError: Error setting realtime scheduler, try running as root (use sudo)

jpieper, 2023-11-09:
The pi3hat is only compatible with Raspberry Pi 3 and 4, and not with the orange pi or any up boards.

Closed 2023-11-09.

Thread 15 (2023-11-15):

Hello, may I ask how I can communicate with pi3hat through SPI? Could you please provide an example?

MaxKingWealth, 2023-11-15:
Hello, may I ask how I can communicate with pi3hat through SPI? Could you please provide an example?

jpieper, 2023-11-15:
The SPI communication registers are documented, but using them directly with anything other than the pi3hat c++ or python library is not supported.

You can read the SPI registers through the C++ library using pi3hat_tool like so:

```
sudo ./pi3hat_tool --read-spi 2,32,6
```

To read 6 bytes from address 32 on bus 2.

MaxKingWealth, 2023-11-15:
I don't have raspberry pie on my end, can't I communicate with PI3hat?

jpieper, 2023-11-15:
You can, but it is not supported.  You will have to read the schematic to understand the RPI pinout and follow the reference manual's instructions for which SPI register contains what data.

MaxKingWealth, 2023-11-15:
OK，Thanks a lot, I will try to do it

Closed 2023-11-15.

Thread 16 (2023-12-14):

Add support for Python 3.11 to pi3hat_tool

JGSuw, 2023-12-14:
I would like to add support for Python 3.11 in building pi3hat_tool. Recently, Python 3.11 headers were added to mjbots/bazel_deps, but this added capability is not currently reflected in the build files for pi3hat. This support would be desirable, since currently python3.11 is the only version that is available for Raspian OS and raspberry pi 4. Older versions, such as 3.7, 3.9, and 3.10, must be built from source, which is time consuming.

I have a local branch that has implemented these changes. The changes are modest, and involves small changes to the following files:

- update the commit hash and checksum of the mjbots/bazel_deps github_archive in [pi3hat/tools/workspace/bazel_deps/repository.bzl](https://github.com/mjbots/pi3hat/blob/master/tools/workspace/bazel_deps/repository.bzl) to [806ba633](https://github.com/mjbots/bazel_deps/commit/80b6a3324b6abb5b630f05a8523730c55218860d)
- udpate multiple config_setting in [pi3hat/BUILD](https://github.com/mjbots/pi3hat/blob/master/BUILD)
- add string '3.11' to pyver in [pi3hat/make_release.py](https://github.com/mjbots/pi3hat/blob/c3563cefe31c66d06e2f5e4faa7c2d31ea34eb14/make_release.py#L57)
- add cc_library pybind11_311 to [pi3hat/tools/workspace/pybind11/package.BUILD](https://github.com/mjbots/pi3hat/blob/master/tools/workspace/pybind11/package.BUILD)
- update PYTHON_SHORT_VERSIONS, ABITAG, PTAG, and bdist_wheel filgroup in [pi3hat/lib/python/BUILD](https://github.com/mjbots/pi3hat/blob/master/lib/python/BUILD)
- update cc_binary _pi3hat_router.so in [pi3hat/lib/python/moteus_pi3hat/BUILD](https://github.com/mjbots/pi3hat/blob/master/lib/python/moteus_pi3hat/BUILD)

I may be missing a few small changes here, but I would like to open a pull request with the permission of @jpieper to review the necessary changes.

jpieper, 2023-12-14:
No need to ask permission, just open!  I may not take it directly, but will certainly use it for guidance.

thestumbler, 2023-12-14:
A couple of years ago I was doing a Python project on the Raspberry Pi whose package took a significant amount of time to build. I discovered `piwheels`, infuriatingly spelled with an S unlike its desktop PC counterpart `wheel`. Don't know if that is of any help to you or not.

JGSuw, 2023-12-14:
@thestumbler not sure if that would help, I'm fairly new to distribution of python packages and OSS in general. I will fork this repo, create new branch with changes, and open a pull request after confirming that all the targets build successfully.

The main thing I need to enable my own use case is that the pi3hat_tools wheel gets built for python 3.11, so that I may install it on my pi4.

Closed 2023-12-14.

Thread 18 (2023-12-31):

no pi3hat detected

BJSingh, 2023-12-31:
When I tried to run sample code even as root user getting error hat not detected. But HAT (r4.4) is attached on Raspberry Pi 4 Model B Rev 1.5

root@raspberrypi:/home/pidemo/pi3hat/lib/python/examples# python3 raw_can_example.py
Traceback (most recent call last):
  File "/home/pidemo/pi3hat/lib/python/examples/raw_can_example.py", line 92, in <module>
    asyncio.run(main())
  File "/usr/lib/python3.9/asyncio/runners.py", line 44, in run
    return loop.run_until_complete(main)
  File "/usr/lib/python3.9/asyncio/base_events.py", line 642, in run_until_complete
    return future.result()
  File "/home/pidemo/pi3hat/lib/python/examples/raw_can_example.py", line 39, in main
    transport = moteus_pi3hat.Pi3HatRouter(can=can_config)
  File "/usr/local/lib/python3.9/dist-packages/moteus_pi3hat/pi3hat_router.py", line 108, in __init__
    self._impl = _pi3hat_router.Pi3HatRouter(options)
RuntimeError: No pi3hat detected

jpieper, 2023-12-31:
We resolved this in the mjbots Discord as likely being a problem with the Raspberry Pi used as a host.

Closed 2023-12-31.

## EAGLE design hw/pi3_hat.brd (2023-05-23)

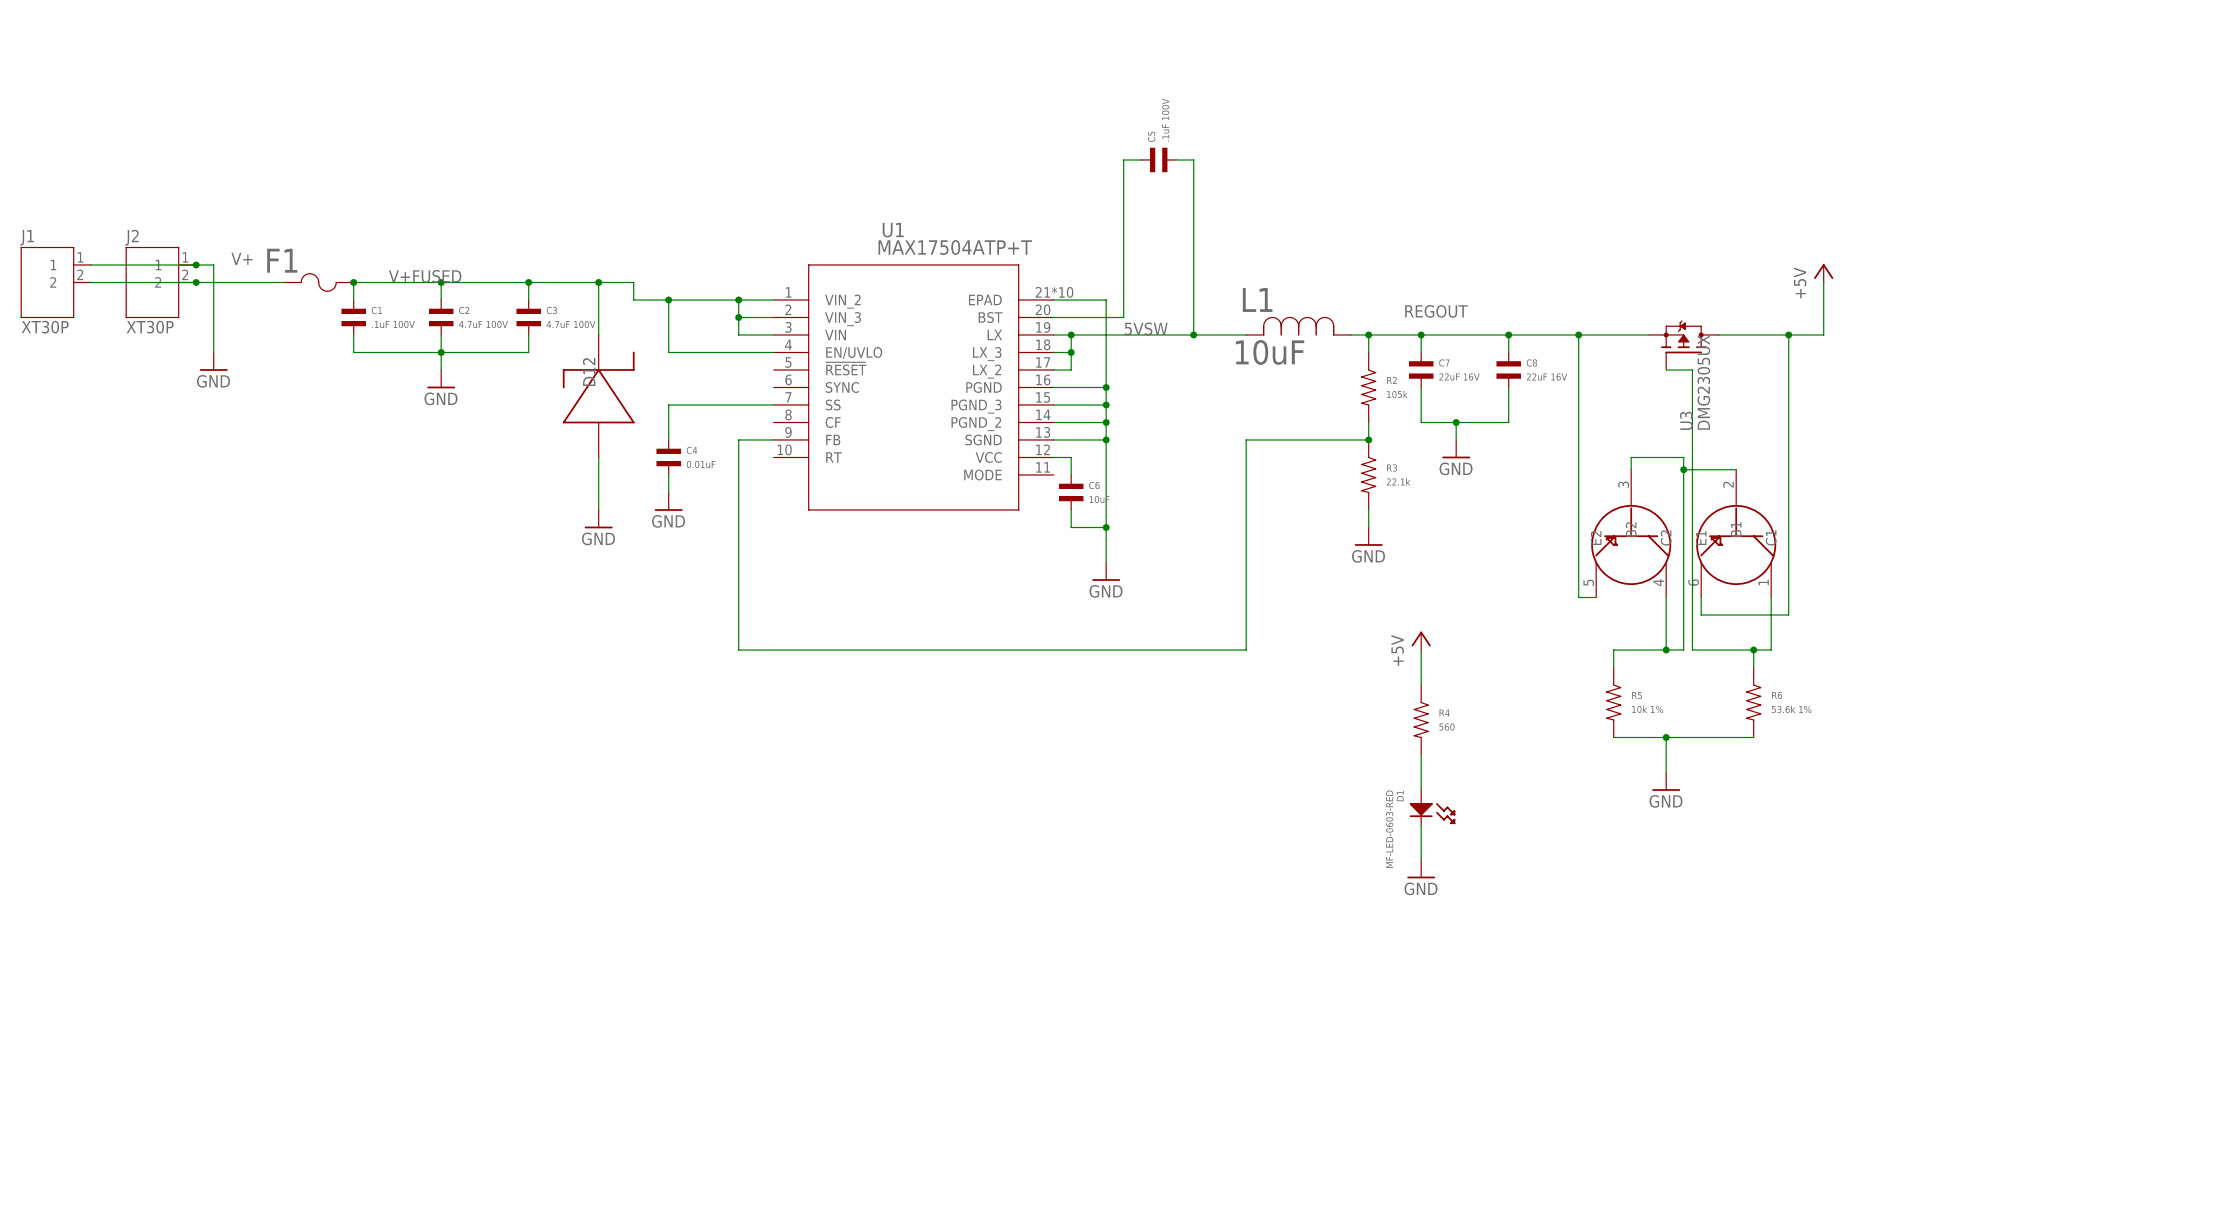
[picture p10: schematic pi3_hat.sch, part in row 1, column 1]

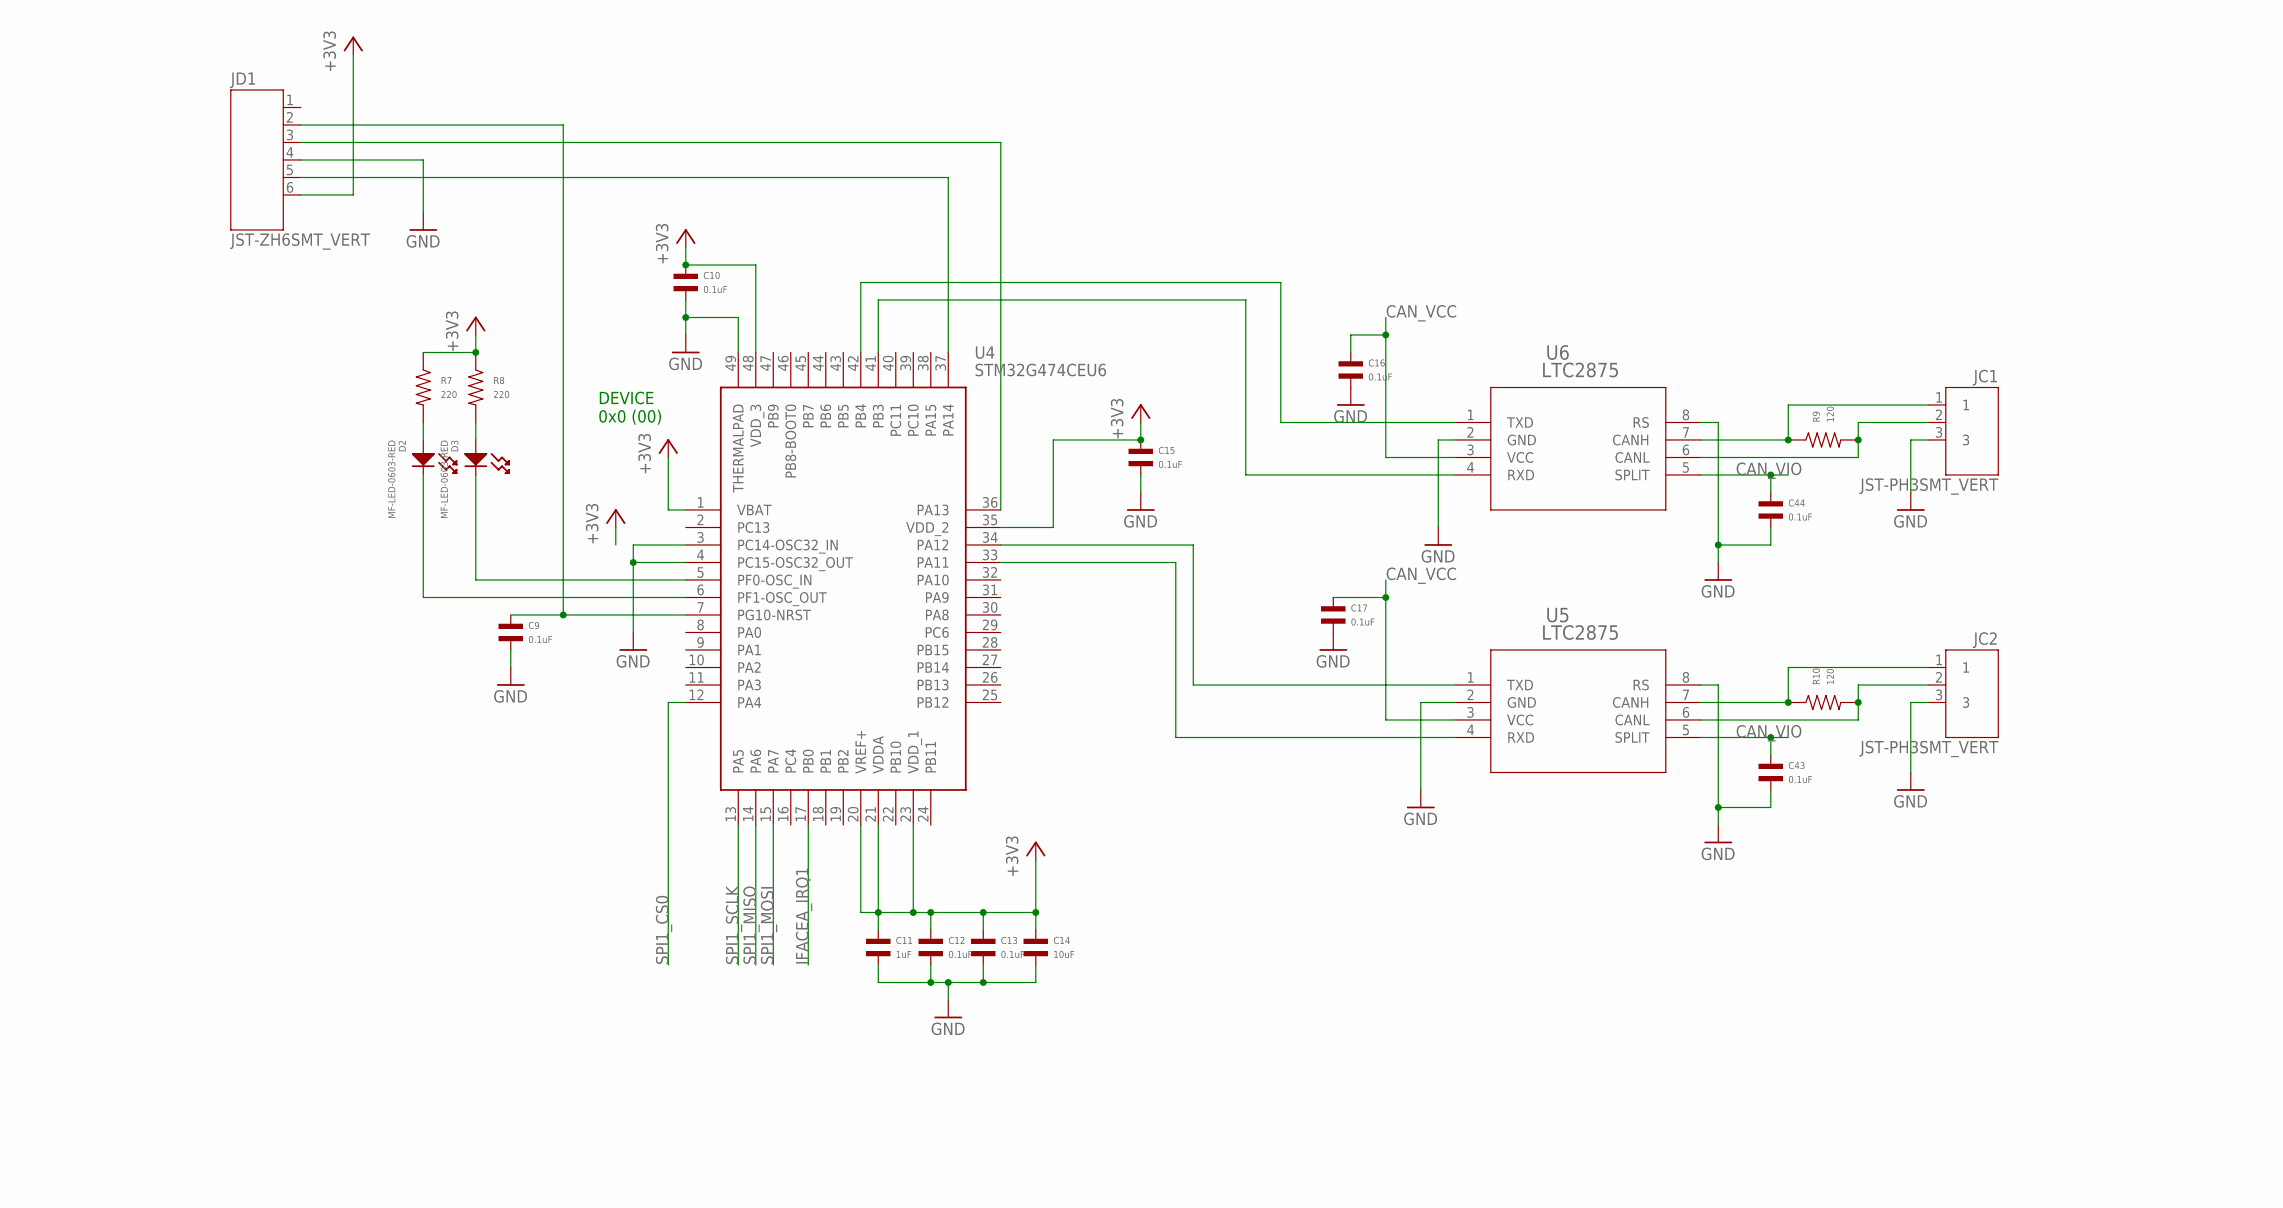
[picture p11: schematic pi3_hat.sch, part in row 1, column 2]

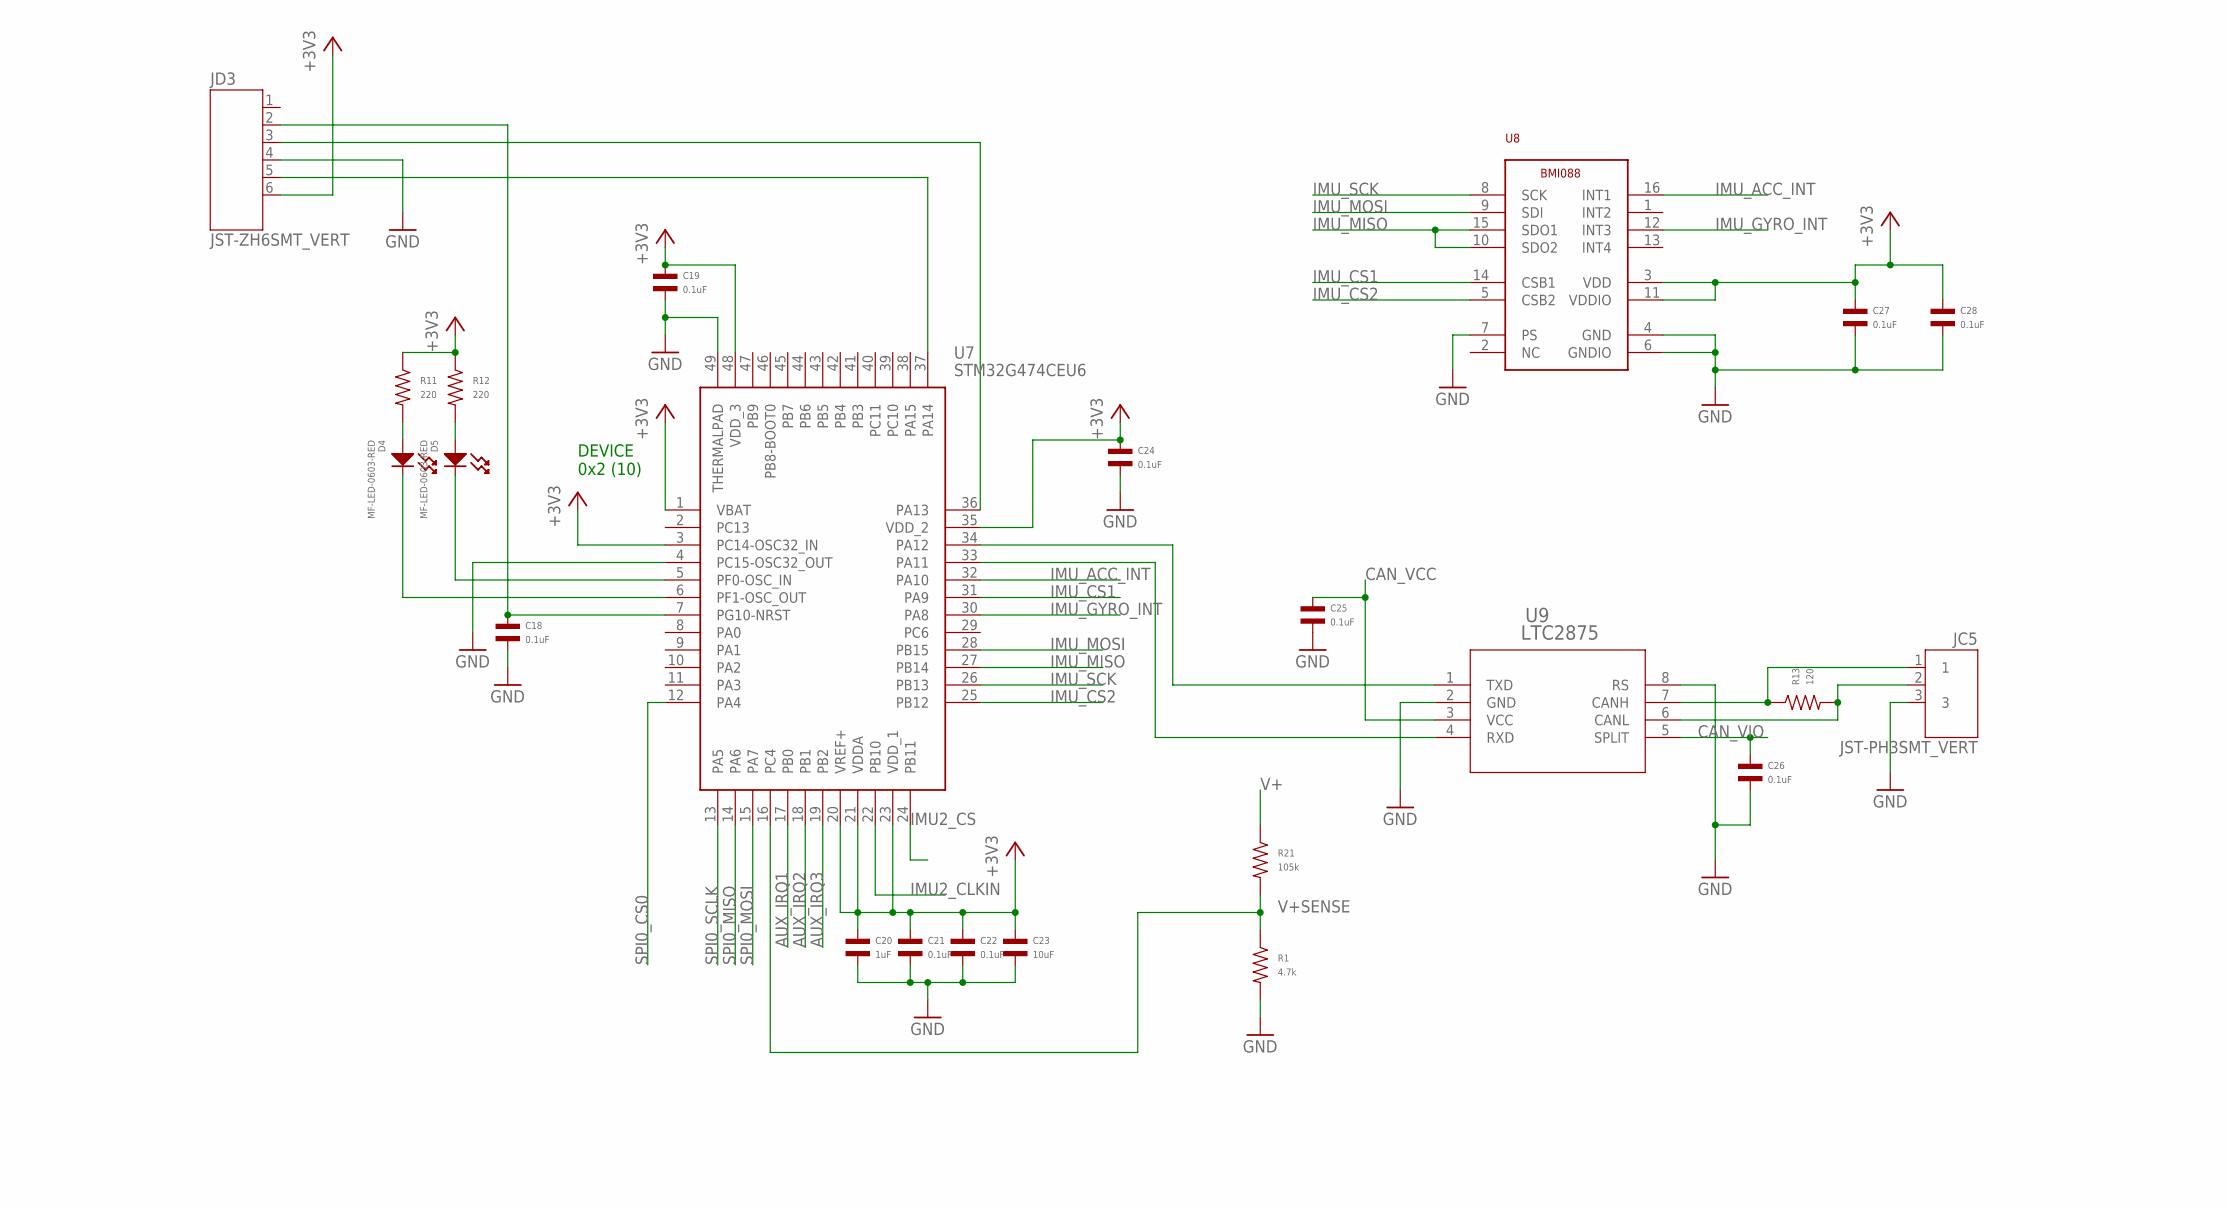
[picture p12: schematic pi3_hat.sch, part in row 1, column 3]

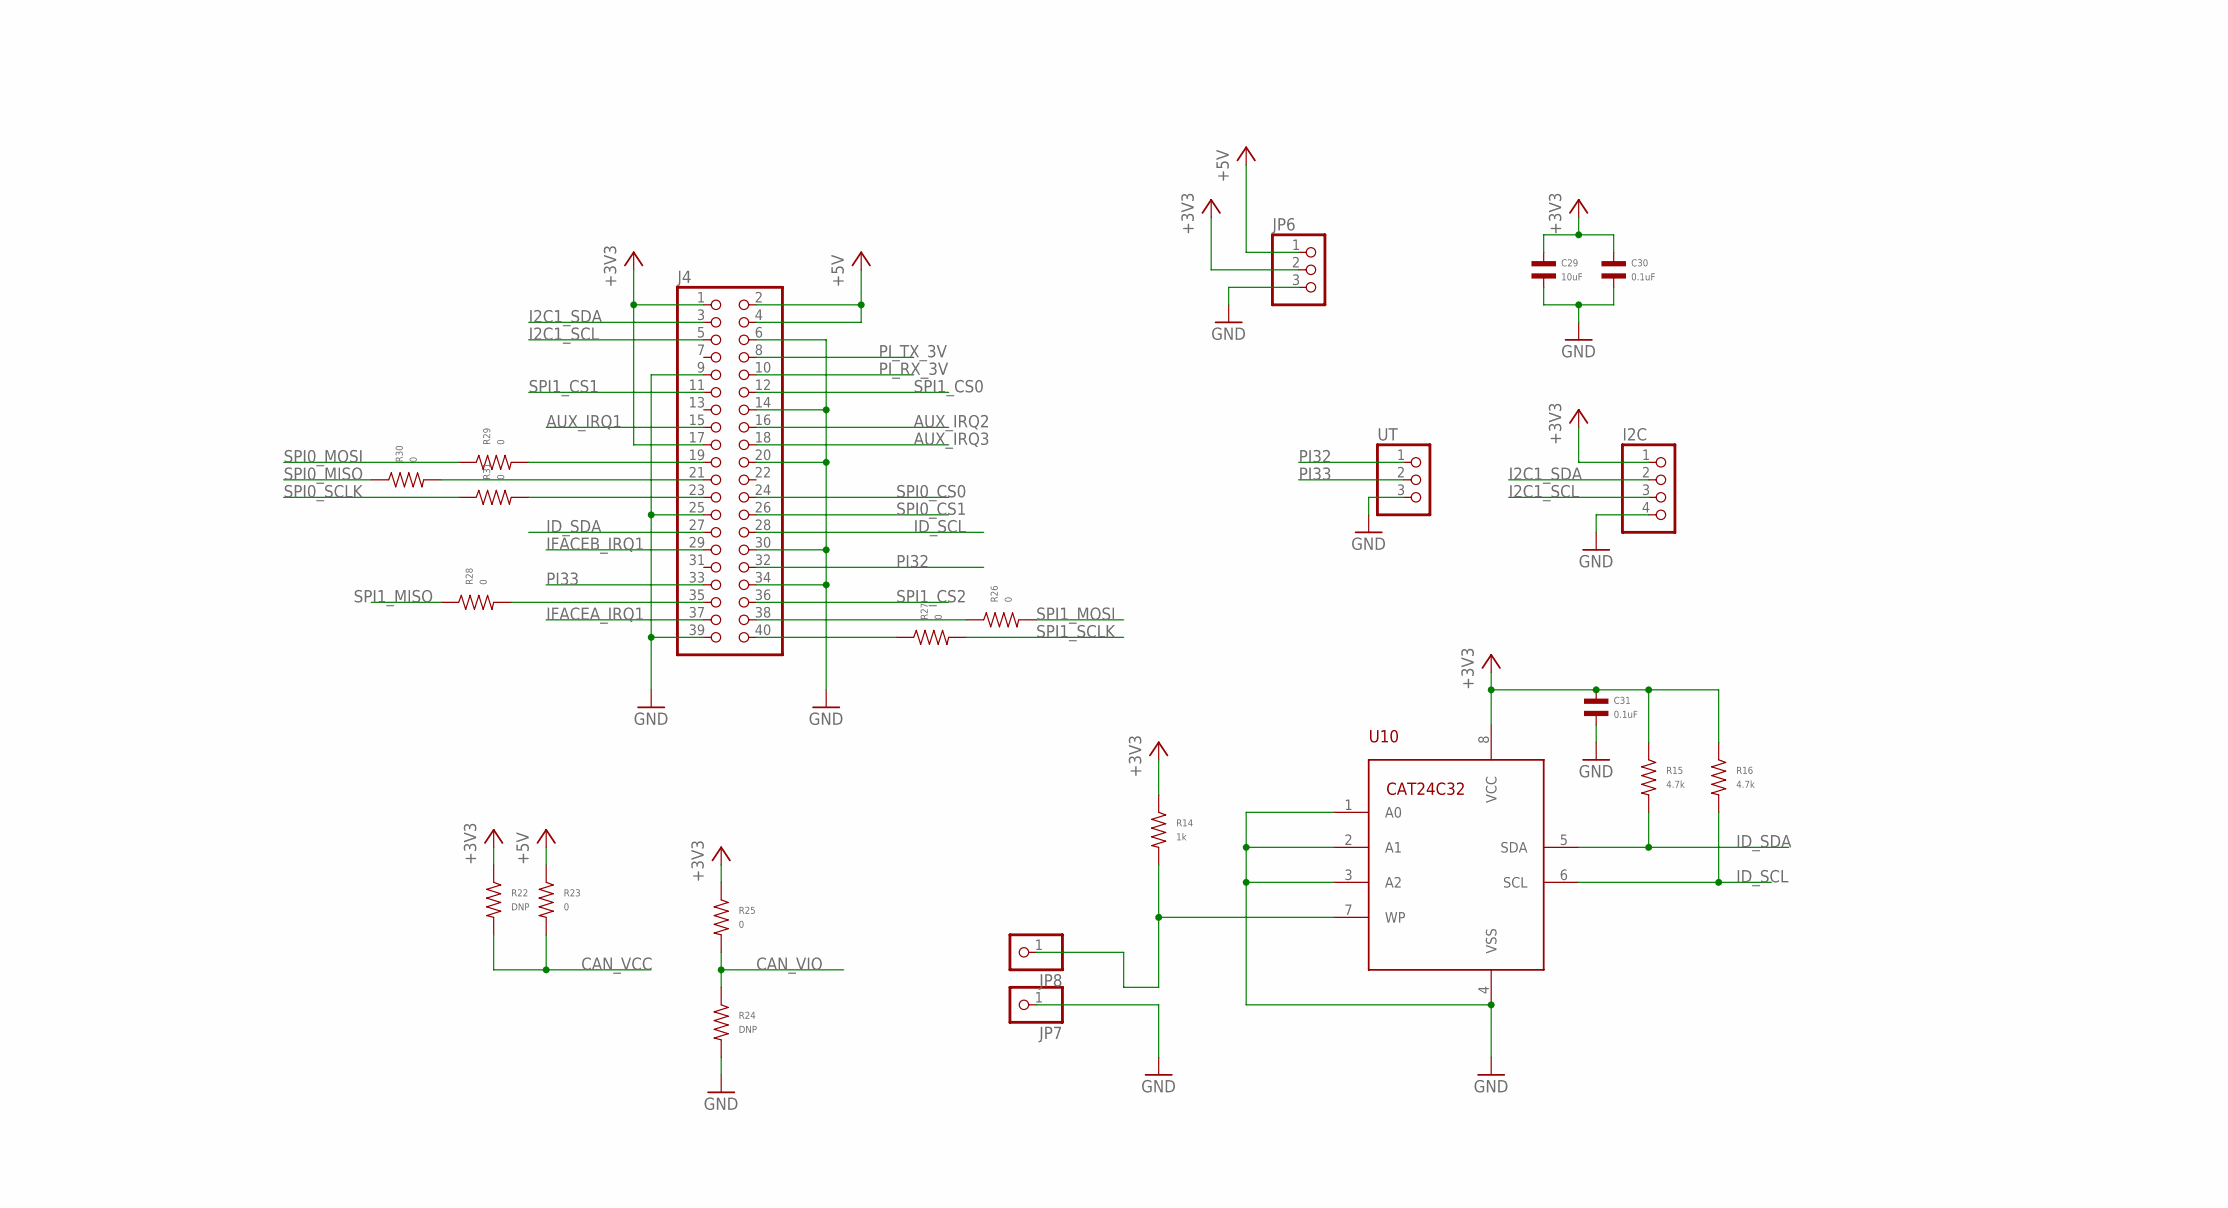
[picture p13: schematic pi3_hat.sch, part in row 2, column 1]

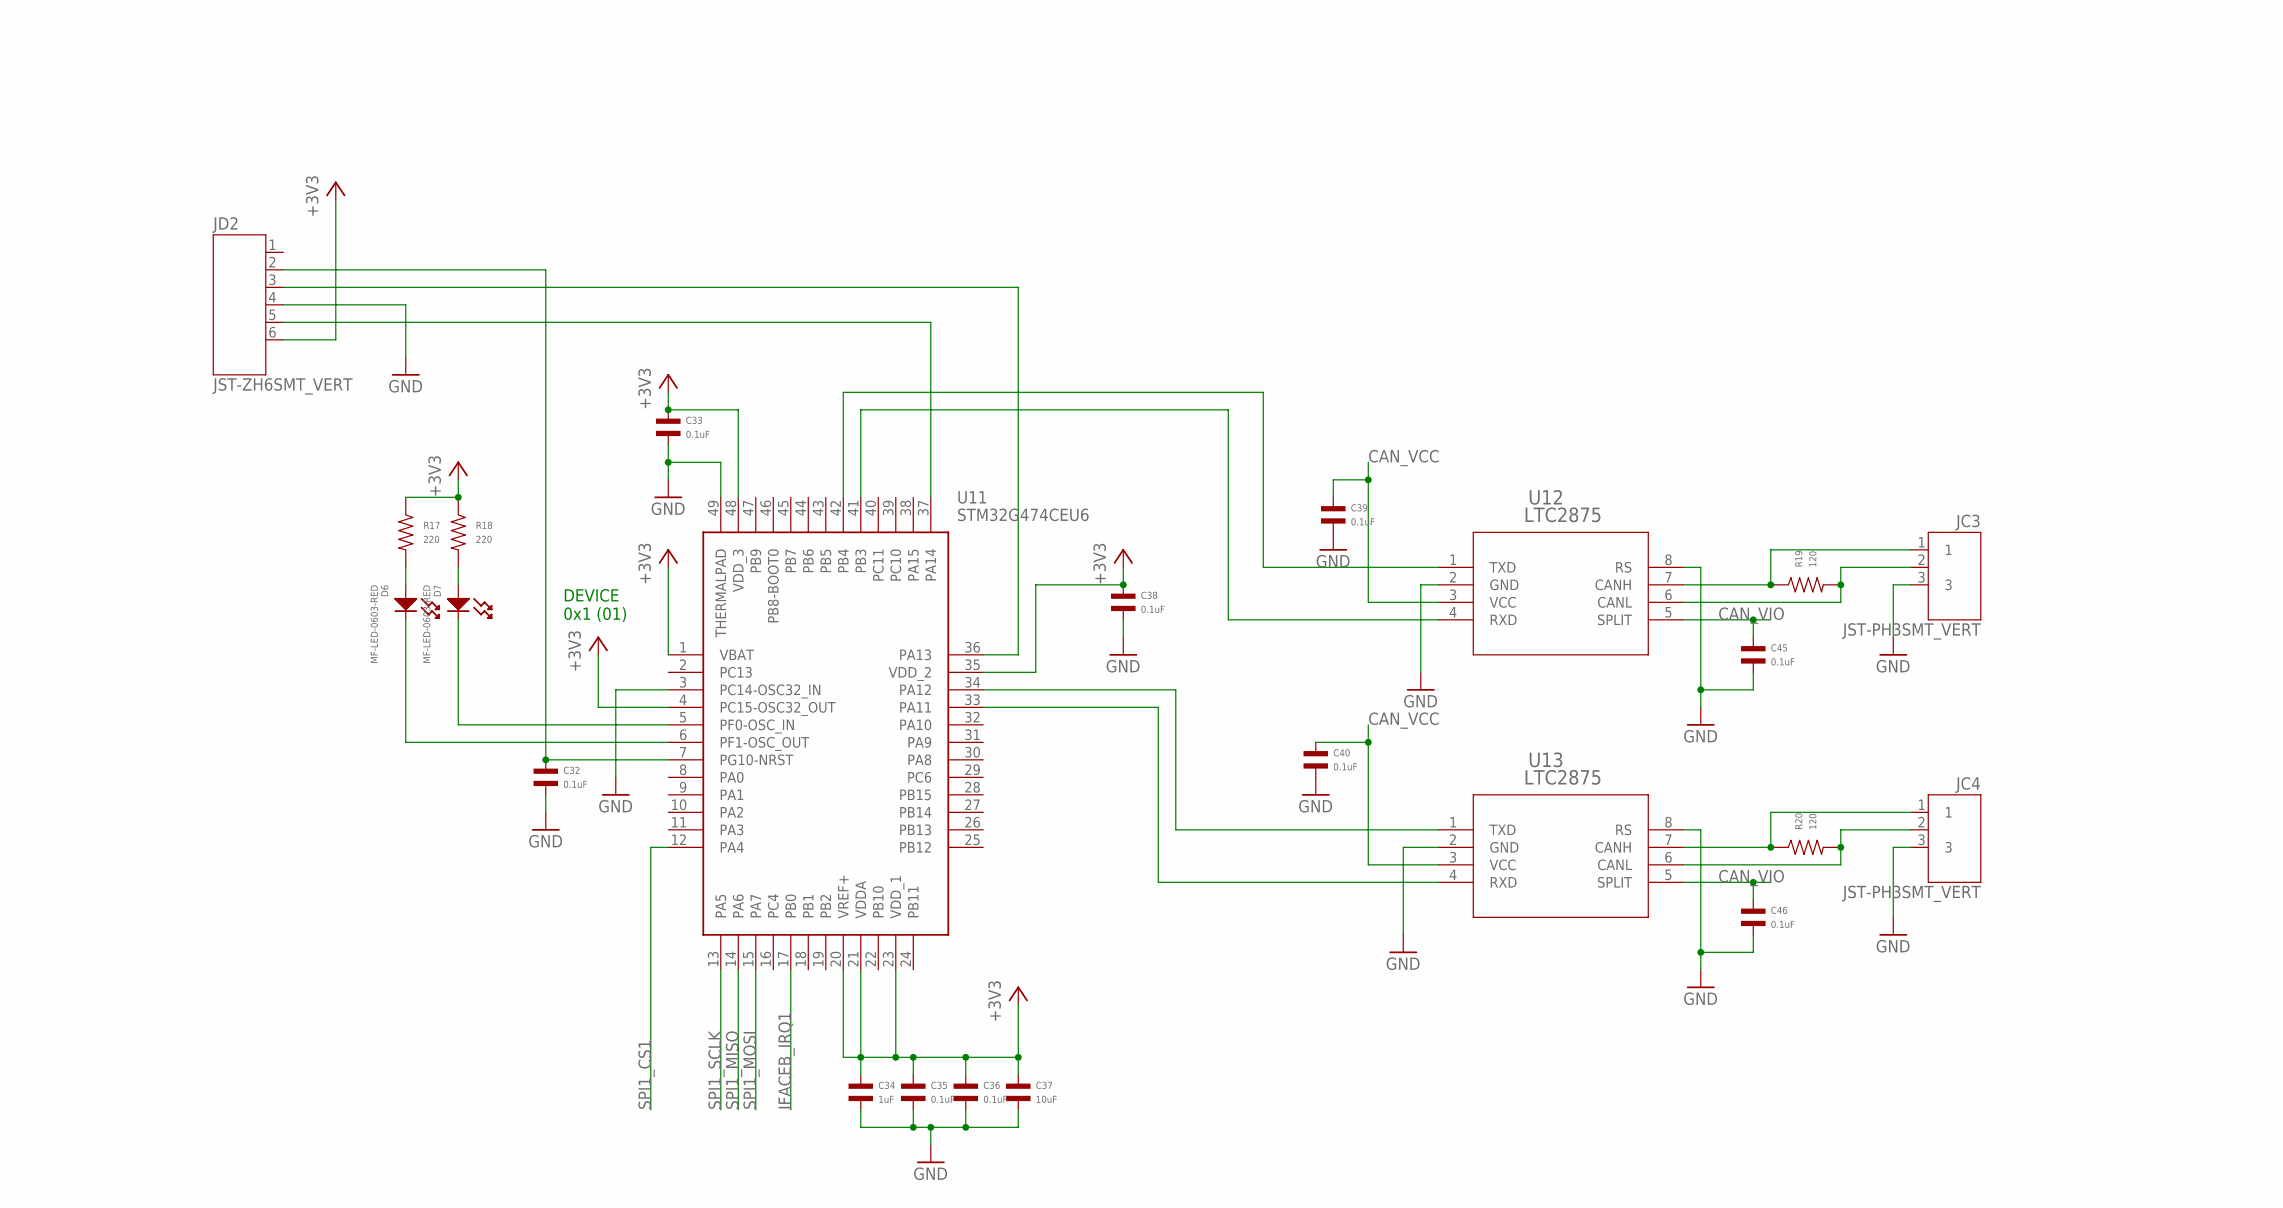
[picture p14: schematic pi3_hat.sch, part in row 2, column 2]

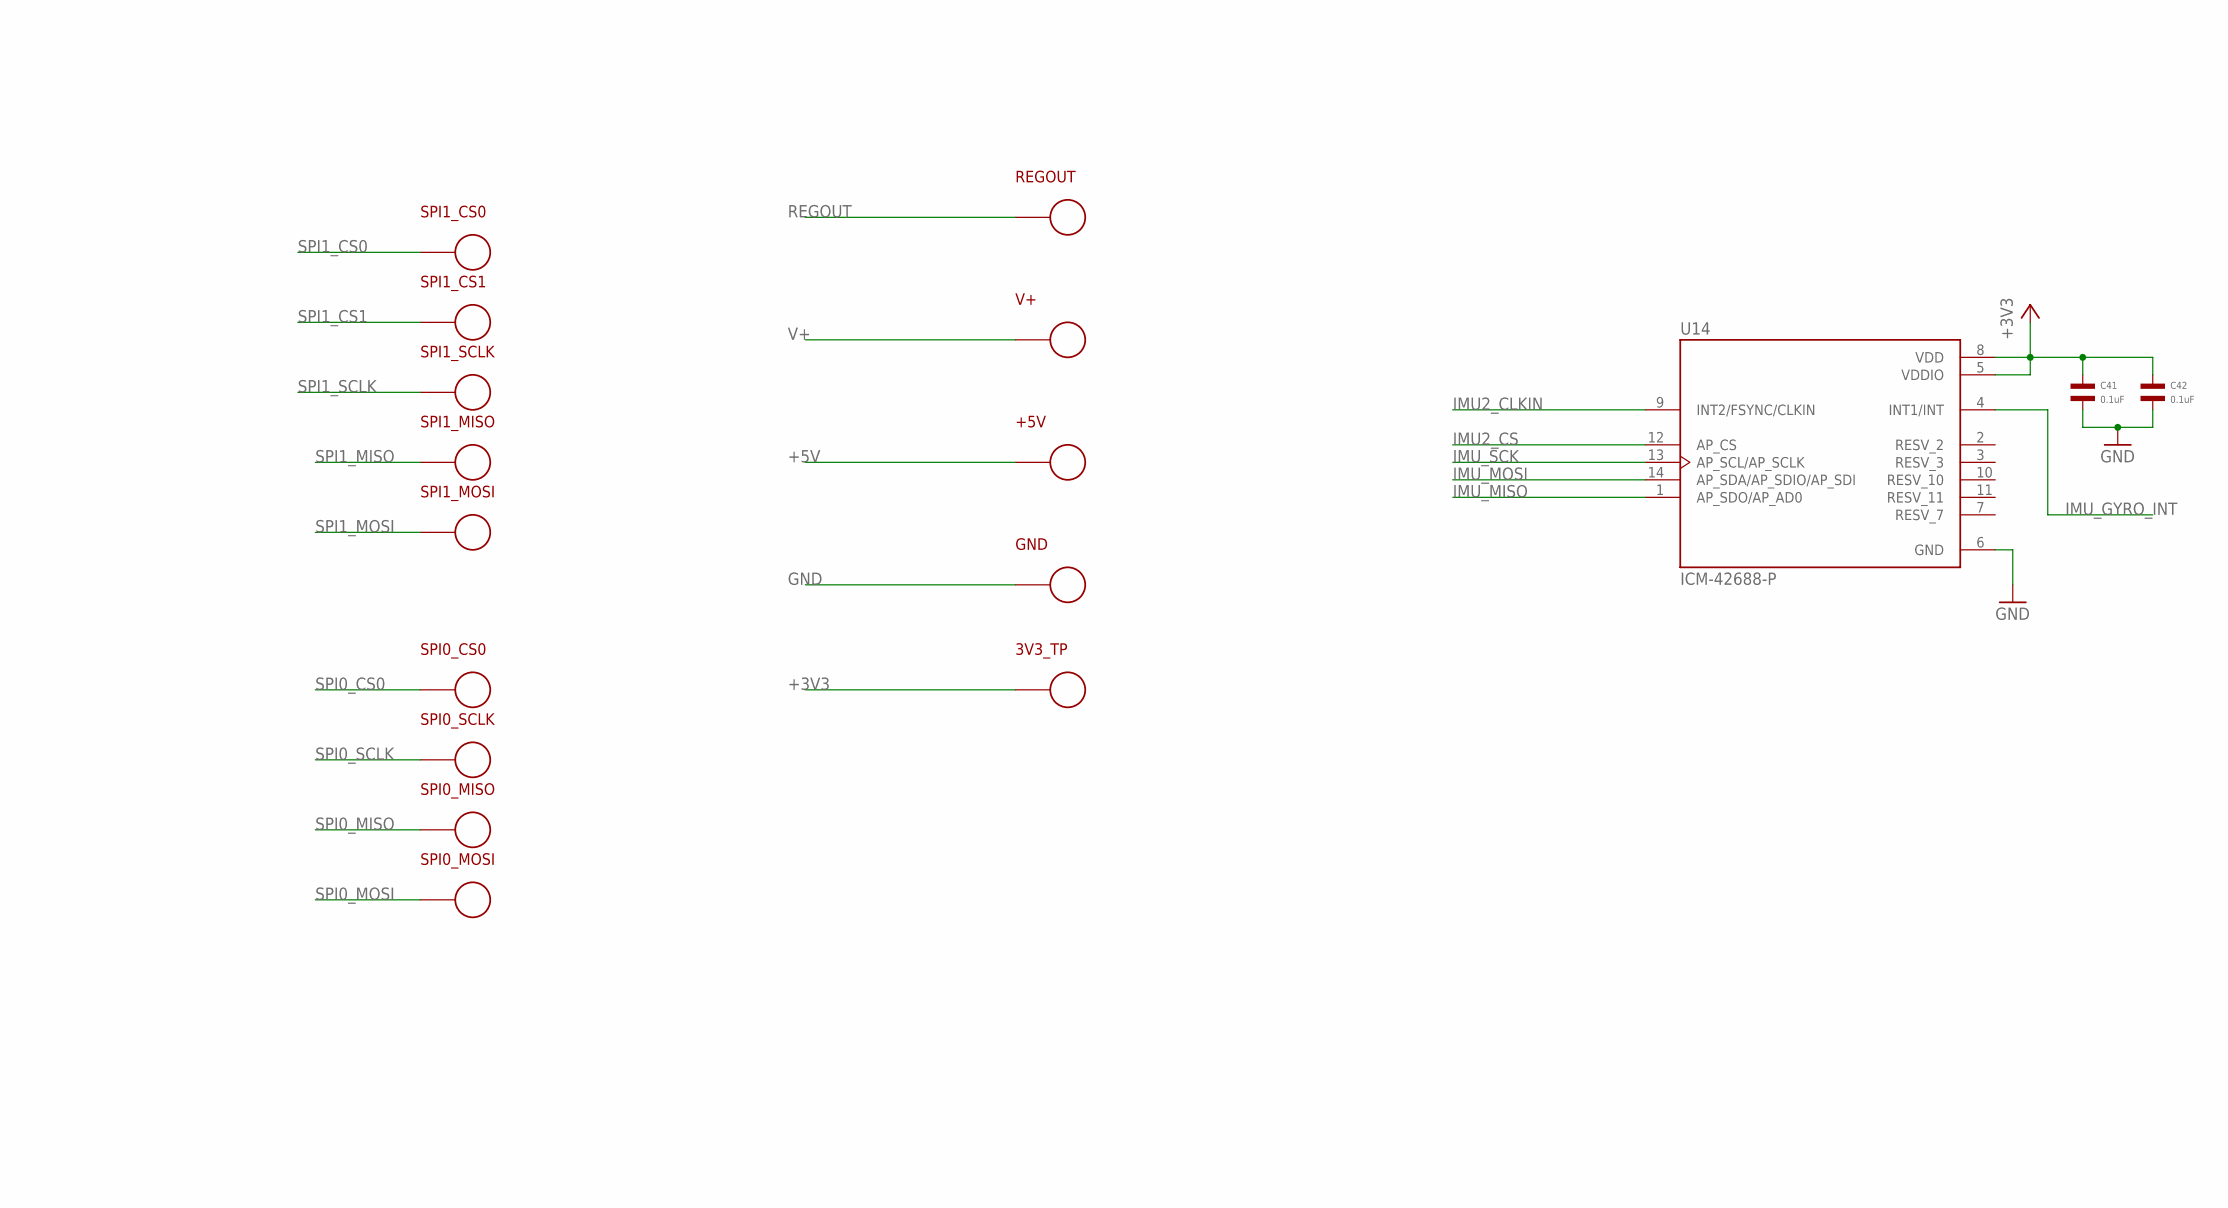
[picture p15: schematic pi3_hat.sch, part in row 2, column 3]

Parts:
3V3_TP: PAD24AWG_PAD; 24AWG_PAD
+5V: PAD24AWG_PAD; 24AWG_PAD
C1, C5: .1uF 100V; C0805; MPN 08051C104KAZ2A
C2, C3: 4.7uF 100V; C1206; MPN GRJ31CC72A475KE01K
C4: 0.01uF; C0603; MPN MF-CAP-0603-0.01uF
C6, C14, C23, C29, C37: 10uF; C1206; MPN MF-CAP-1206-10uF
C7, C8: 22uF 16V; C1210; MPN CL32A226KOJNNNE
C9, C10, C12, C13, C15, C16, C17, C18, C19, C21, C22, C24, C25, C26, C27, C28, C30, C31, C32, C33, C35, C36, C38, C39, C40, C41, C42, C43, C44, C45, C46: 0.1uF; C0402; MPN MF-CAP-0402-0.1uF
C11, C20, C34: 1uF; C0402; MPN MF-CAP-0402-1uF
D1, D2, D4, D6: MF-LED-0603-RED; LED0603
D3, D5, D7: MF-LED-0603-RED; LED0603; MPN MF-LED-0603-GREEN
D12: SMF; MPN SMF51A
F1: MFU0603FF04000P100; FUS_VISHAY_MFU0603; MPN 0686F4000-01
GND: PAD24AWG_PAD; 24AWG_PAD
I2C: PINHD-1X4; 1X04; MPN MF-CON-2.54mm-01x04
J1, J2: XT30P; MPN XT30UPB-M
J4: PI3_HEADER2X20-FLIP; 2X20FLIP; MPN PPPC202LFBN-RC
JC1, JC2, JC3, JC4, JC5: JST-PH3SMT_VERT; JST_B3B_PH-SM4-TB(LF)(SN); MPN B3B-PH-SM4-TB(LF)(SN)
JD1, JD2, JD3: JST-ZH6SMT_VERT; JST_B6B-ZR-SM4-TF(LF)(SN); MPN B6B-ZR-SM4-TF(LF)(SN)
JP6: PINHD-1X3; 1X03; MPN MF-CON-2.54mm-01x03
JP7, JP8: PINHD-1X1; 1X01
L1: 10uF; IND_YUDEN_NS10165_YDN; MPN NS10165T100MNA
R1, R15, R16: 4.7k; R0402; MPN MF-RES-0402-4.7K
R2, R21: 105k; R0402; MPN RC0402FR-07105KL
R3: 22.1k; R0402; MPN RC0402FR-0722K1L
R4: 560; R0402; MPN MF-RES-0402-560
R5: 10k 1%; R0603; MPN RC0603FR-0710KL
R6: 53.6k 1%; R0603; MPN RC0603FR-0753K6L
R7, R8, R11, R12, R17, R18: 220; R0402; MPN MF-RES-0402-220
R9, R10, R13, R19, R20: 120; R0402; MPN RC0402FR-07120RL
R14: 1k; R0402; MPN MF-RES-0402-1K
R22, R24: DNP; R0402; MPN MF-RES-0402-0
R23, R25, R26, R27, R28, R29, R30, R31: 0; R0402; MPN MF-RES-0402-0
REGOUT: PAD24AWG_PAD; 24AWG_PAD
SPI0_CS0, SPI0_MISO, SPI0_MOSI, SPI0_SCLK, SPI1_CS0, SPI1_CS1, SPI1_MISO, SPI1_MOSI, SPI1_SCLK: PAD24AWG_PAD; 24AWG_PAD
U1: MAX17504ATP+T; 21-0140L_T2055-4_MXM; MPN MAX17504ATP+T
U2: DMMT5401; SOT26; MPN DMMT5401-7-F
U3: DMG2305UX; SOT23; MPN AO3415A
U4, U7, U11: STM32G474CEU6; QFN50P700X700X60-49N; MPN STM32G474CEU6
U5, U6, U9, U12, U13: LTC2875; SOIC8; MPN TCAN1057AEVDRQ1
U8: BMI088LGA16; LGA16; MPN BMI088
U10: CAT24C32UDFN8; UDFN8_2X3_ONS; MPN CAT24C32HU4I-GT3
U14: ICM-42688-P; PQFN50P300X250X97-14N; MPN ICM-42688-P
UT: PINHD-1X3; 1X03; MPN MF-CON-2.54mm-01x03
V+: PAD24AWG_PAD; 24AWG_PAD

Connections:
5VSW: C5.P$2, L1.2, U1.17 (LX_2), U1.18 (LX_3), U1.19 (LX)
+3V3: 3V3_TP.P$1, C10.P$1, C11.P$1, C12.P$1, C13.P$1, C14.P$1, C15.P$1, C19.P$1, C20.P$1, C21.P$1, C22.P$1, C23.P$1, C24.P$1, C27.P$1, C28.P$1, C29.P$1, C30.P$1, C31.P$1, C33.P$1, C34.P$1, C35.P$1, C36.P$1, C37.P$1, C38.P$1, C41.P$1, C42.P$1, I2C.1, J4.1, J4.17, JD1.6, JD2.6, JD3.6, JP6.2, R7.P$1, R8.P$1, R11.P$1, R12.P$1, R14.P$1, R15.P$1, R16.P$1, R17.P$1, R18.P$1, R22.P$1, R25.P$1, U4.1 (VBAT), U4.20 (VREF+), U4.21 (VDDA), U4.23 (VDD_1), U4.35 (VDD_2), U4.48 (VDD_3), U7.1 (VBAT), U7.3 (PC14-OSC32_IN), U7.20 (VREF+), U7.21 (VDDA), U7.23 (VDD_1), U7.35 (VDD_2), U7.48 (VDD_3), U8.3 (VDD), U8.11 (VDDIO), U10.8 (VCC), U11.1 (VBAT), U11.4 (PC15-OSC32_OUT), U11.20 (VREF+), U11.21 (VDDA), U11.23 (VDD_1), U11.35 (VDD_2), U11.48 (VDD_3), U14.5 (VDDIO), U14.8 (VDD)
+5V: +5V.P$1, J4.2, J4.4, JP6.1, R4.P$1, R23.P$1, U2.6 (E1), U3.3 (D)
AUX_IRQ1: J4.15, U7.17 (PB0)
AUX_IRQ2: J4.16, U7.18 (PB1)
AUX_IRQ3: J4.18, U7.19 (PB2)
CAN_VCC: C16.P$1, C17.P$1, C25.P$1, C39.P$1, C40.P$1, R22.P$2, R23.P$2, U5.3 (VCC), U6.3 (VCC), U9.3 (VCC), U12.3 (VCC), U13.3 (VCC)
CAN_VIO: C26.P$1, C43.P$1, C44.P$1, C45.P$1, C46.P$1, R24.P$1, R25.P$2, U5.5 (SPLIT), U6.5 (SPLIT), U9.5 (SPLIT), U12.5 (SPLIT), U13.5 (SPLIT)
FB: R2.P$2, R3.P$1, U1.9 (FB)
GND: C1.P$2, C2.P$2, C3.P$2, C4.P$2, C6.P$2, C7.P$2, C8.P$2, C9.P$2, C10.P$2, C11.P$2, C12.P$2, C13.P$2, C14.P$2, C15.P$2, C16.P$2, C17.P$2, C18.P$2, C19.P$2, C20.P$2, C21.P$2, C22.P$2, C23.P$2, C24.P$2, C25.P$2, C26.P$2, C27.P$2, C28.P$2, C29.P$2, C30.P$2, C31.P$2, C32.P$2, C33.P$2, C34.P$2, C35.P$2, C36.P$2, C37.P$2, C38.P$2, C39.P$2, C40.P$2, C41.P$2, C42.P$2, C43.P$2, C44.P$2, C45.P$2, C46.P$2, D1.CATHODE, D12.A, GND.P$1, I2C.4, J1.1, J2.1, J4.6, J4.9, J4.14, J4.20, J4.25, J4.30, J4.34, J4.39, JC1.3, JC2.3, JC3.3, JC4.3, JC5.3, JD1.4, JD2.4, JD3.4, JP6.3, JP7.1, R1.P$2, R3.P$2, R5.P$2, R6.P$2, R24.P$2, U1.13 (SGND), U1.14 (PGND_2), U1.15 (PGND_3), U1.16 (PGND), U1.21 (EPAD), U1.22 (EPAD), U1.23 (EPAD), U1.24 (EPAD), U1.25 (EPAD), U1.26 (EPAD), U1.27 (EPAD), U1.28 (EPAD), U1.29 (EPAD), U1.30 (EPAD), U4.3 (PC14-OSC32_IN), U4.4 (PC15-OSC32_OUT), U4.49 (THERMALPAD), U5.2 (GND), U5.8 (RS), U6.2 (GND), U6.8 (RS), U7.4 (PC15-OSC32_OUT), U7.49 (THERMALPAD), U8.4 (GND), U8.6 (GNDIO), U8.7 (PS), U9.2 (GND), U9.8 (RS), U10.1 (A0), U10.2 (A1), U10.3 (A2), U10.4 (VSS), U11.3 (PC14-OSC32_IN), U11.49 (THERMALPAD), U12.2 (GND), U12.8 (RS), U13.2 (GND), U13.8 (RS), U14.6 (GND), UT.3
I2C1_SCL: I2C.3, J4.5
I2C1_SDA: I2C.2, J4.3
ID_SCL: J4.28, R16.P$2, U10.6 (SCL)
ID_SDA: J4.27, R15.P$2, U10.5 (SDA)
IFACEA_IRQ1: J4.37, U4.17 (PB0)
IFACEB_IRQ1: J4.29, U11.17 (PB0)
IMU2_CLKIN: U7.22 (PB10), U14.9 (INT2/FSYNC/CLKIN)
IMU2_CS: U7.24 (PB11), U14.12 (AP_CS)
IMU_ACC_INT: U7.32 (PA10), U8.16 (INT1)
IMU_CS1: U7.31 (PA9), U8.14 (CSB1)
IMU_CS2: U7.25 (PB12), U8.5 (CSB2)
IMU_GYRO_INT: U7.30 (PA8), U8.12 (INT3), U14.4 (INT1/INT)
IMU_MISO: U7.27 (PB14), U8.10 (SDO2), U8.15 (SDO1), U14.1 (AP_SDO/AP_AD0)
IMU_MOSI: U7.28 (PB15), U8.9 (SDI), U14.14 (AP_SDA/AP_SDIO/AP_SDI)
IMU_SCK: U7.26 (PB13), U8.8 (SCK), U14.13 (AP_SCL/AP_SCLK)
unnamed: R5.P$1, U2.2 (B1), U2.3 (B2), U2.4 (C2)
unnamed: JC1.1, R9.P$1, U6.7 (CANH)
unnamed: J4.38, R26.P$1
unnamed: JC1.2, R9.P$2, U6.6 (CANL)
unnamed: R6.P$1, U2.1 (C1), U3.1 (G)
unnamed: J4.40, R27.P$1
unnamed: JC2.1, R10.P$1, U5.7 (CANH)
unnamed: JC2.2, R10.P$2, U5.6 (CANL)
unnamed: D1.ANODE, R4.P$2
unnamed: J4.35, R28.P$2
unnamed: U4.33 (PA11), U5.4 (RXD)
unnamed: J4.19, R29.P$2
unnamed: C9.P$1, JD1.2, U4.7 (PG10-NRST)
unnamed: C5.P$1, U1.20 (BST)
unnamed: JD1.3, U4.36 (PA13)
unnamed: JD1.5, U4.37 (PA14)
unnamed: U4.41 (PB3), U6.4 (RXD)
unnamed: U4.42 (PB4), U6.1 (TXD)
unnamed: C4.P$1, U1.7 (SS)
unnamed: J4.21, R30.P$2
unnamed: C6.P$1, U1.12 (VCC)
unnamed: J4.23, R31.P$2
unnamed: JC3.1, R19.P$1, U12.7 (CANH)
unnamed: JC3.2, R19.P$2, U12.6 (CANL)
unnamed: JC4.1, R20.P$1, U13.7 (CANH)
unnamed: JC4.2, R20.P$2, U13.6 (CANL)
unnamed: D3.ANODE, R8.P$2
unnamed: D3.CATHODE, U4.5 (PF0-OSC_IN)
unnamed: D2.ANODE, R7.P$2
unnamed: D2.CATHODE, U4.6 (PF1-OSC_OUT)
unnamed: C32.P$1, JD2.2, U11.7 (PG10-NRST)
unnamed: JD2.3, U11.36 (PA13)
unnamed: JD2.5, U11.37 (PA14)
unnamed: D7.ANODE, R18.P$2
unnamed: D7.CATHODE, U11.5 (PF0-OSC_IN)
unnamed: D6.ANODE, R17.P$2
unnamed: D6.CATHODE, U11.6 (PF1-OSC_OUT)
unnamed: U11.33 (PA11), U13.4 (RXD)
unnamed: U11.34 (PA12), U13.1 (TXD)
unnamed: U11.41 (PB3), U12.4 (RXD)
unnamed: U11.42 (PB4), U12.1 (TXD)
unnamed: JP8.1, R14.P$2, U10.7 (WP)
unnamed: JC5.1, R13.P$1, U9.7 (CANH)
unnamed: JC5.2, R13.P$2, U9.6 (CANL)
unnamed: C18.P$1, JD3.2, U7.7 (PG10-NRST)
unnamed: JD3.3, U7.36 (PA13)
unnamed: JD3.5, U7.37 (PA14)
unnamed: D5.ANODE, R12.P$2
unnamed: D5.CATHODE, U7.5 (PF0-OSC_IN)
unnamed: D4.ANODE, R11.P$2
unnamed: D4.CATHODE, U7.6 (PF1-OSC_OUT)
unnamed: U7.33 (PA11), U9.4 (RXD)
unnamed: U7.34 (PA12), U9.1 (TXD)
unnamed: U4.34 (PA12), U5.1 (TXD)
PI32: J4.32, UT.1
PI33: J4.33, UT.2
PI_RX_3V: J4.10
PI_TX_3V: J4.8
REGOUT: C7.P$1, C8.P$1, L1.1, R2.P$1, REGOUT.P$1, U2.5 (E2), U3.2 (S)
SPI0_CS0: J4.24, SPI0_CS0.P$1, U7.12 (PA4)
SPI0_CS1: J4.26
SPI0_MISO: R30.P$1, SPI0_MISO.P$1, U7.14 (PA6)
SPI0_MOSI: R29.P$1, SPI0_MOSI.P$1, U7.15 (PA7)
SPI0_SCLK: R31.P$1, SPI0_SCLK.P$1, U7.13 (PA5)
SPI1_CS0: J4.12, SPI1_CS0.P$1, U4.12 (PA4)
SPI1_CS1: J4.11, SPI1_CS1.P$1, U11.12 (PA4)
SPI1_CS2: J4.36
SPI1_MISO: R28.P$1, SPI1_MISO.P$1, U4.14 (PA6), U11.14 (PA6)
SPI1_MOSI: R26.P$2, SPI1_MOSI.P$1, U4.15 (PA7), U11.15 (PA7)
SPI1_SCLK: R27.P$2, SPI1_SCLK.P$1, U4.13 (PA5), U11.13 (PA5)
V+: F1.1, J1.2, J2.2, R21.P$1, V+.P$1
V+FUSED: C1.P$1, C2.P$1, C3.P$1, D12.C, F1.2, U1.1 (VIN_2), U1.2 (VIN_3), U1.3 (VIN), U1.4 (EN/UVLO)
V+SENSE: R1.P$1, R21.P$2, U7.16 (PC4)

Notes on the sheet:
DEVICE 0x2 (10)
DEVICE 0x0 (00)
DEVICE 0x1 (01)

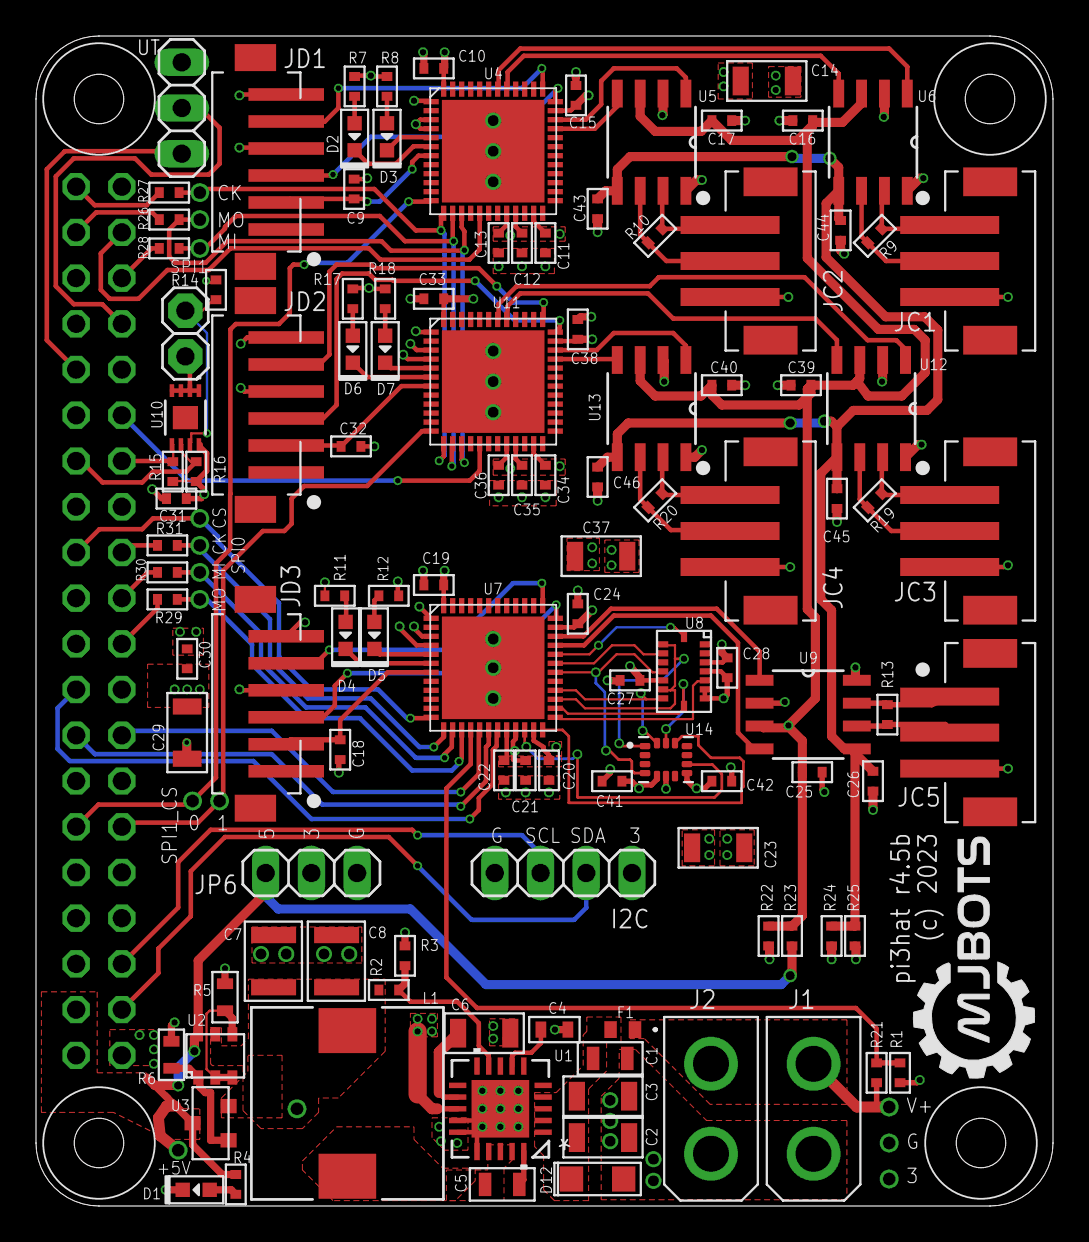
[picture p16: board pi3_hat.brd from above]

Board: 4 copper layers, 56.5 x 65.0 mm, 131 parts (1 on the bottom side), 94 nets.

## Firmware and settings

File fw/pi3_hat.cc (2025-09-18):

// Copyright 2023 mjbots Robotic Systems, LLC.  info@mjbots.com
//
// Licensed under the Apache License, Version 2.0 (the "License");
// you may not use this file except in compliance with the License.
// You may obtain a copy of the License at
//
//     http://www.apache.org/licenses/LICENSE-2.0
//
// Unless required by applicable law or agreed to in writing, software
// distributed under the License is distributed on an "AS IS" BASIS,
// WITHOUT WARRANTIES OR CONDITIONS OF ANY KIND, either express or implied.
// See the License for the specific language governing permissions and
// limitations under the License.

#include <atomic>
#include <cstring>

#include "mbed.h"

#include "mjlib/base/inplace_function.h"
#include "mjlib/base/string_span.h"

#include "fw/can_bridge.h"
#include "fw/cpu_meter.h"
#include "fw/device_info.h"
#include "fw/fdcan.h"
#include "fw/imu.h"
#include "fw/millisecond_timer.h"
#include "fw/register_spi_slave.h"
#include "fw/rf_transceiver.h"

namespace fw {
namespace {

RegisterSPISlave::Pins MakeSpiPins() {
  RegisterSPISlave::Pins result;
  result.mosi = PA_7;
  result.miso = PA_6;
  result.sclk = PA_5;
  result.ssel = PA_4;
  result.status_led = PF_0;

  return result;
}

CanBridge::Pins MakeCanPins() {
  CanBridge::Pins result;
  result.irq_name = PB_0;
  return result;
}

class CanApplication {
 public:
  CanApplication(fw::MillisecondTimer* timer)
      : timer_(timer) {}

  void Poll() {
    cpu_meter_.Poll();
    bridge_.Poll();
  }

  void PollMillisecond() {
    cpu_meter_.PollMillisecond();
    spi_.PollMillisecond();
    bridge_.PollMillisecond();
  }

  fw::MillisecondTimer* const timer_;

  fw::FDCan can1_{[]() {
      fw::FDCan::Options o;
      o.td = PB_4;
      o.rd = PB_3;
      o.slow_bitrate = 1000000;
      o.fast_bitrate = 5000000;
      o.fdcan_frame = true;
      o.bitrate_switch = true;
      o.automatic_retransmission = true;
      return o;
    }()
  };
  fw::FDCan can2_{[]() {
      fw::FDCan::Options o;
      o.td = PA_12;
      o.rd = PA_11;
      o.slow_bitrate = 1000000;
      o.fast_bitrate = 5000000;
      o.fdcan_frame = true;
      o.bitrate_switch = true;
      o.automatic_retransmission = true;
      return o;
    }()
  };

  CpuMeter cpu_meter_;
  CanBridge bridge_{timer_, &can1_, &can2_, MakeCanPins()};
  DeviceInfo device_info_;

  RegisterSPISlave spi_{
    timer_,
    MakeSpiPins(),
    [this](uint16_t address) {
      if (CpuMeter::IsSpiAddress(address)) {
        return cpu_meter_.ISR_Start(address);
      }
      if (CanBridge::IsSpiAddress(address)) {
        return bridge_.ISR_Start(address);
      }
      if (DeviceInfo::IsSpiAddress(address)) {
        return device_info_.ISR_Start(address);
      }
      return RegisterSPISlave::Buffer();
    },
    [this](uint16_t address, int bytes) {
      if (CpuMeter::IsSpiAddress(address)) {
        cpu_meter_.ISR_End(address, bytes);
      }
      if (CanBridge::IsSpiAddress(address)) {
        bridge_.ISR_End(address, bytes);
      }
      if (DeviceInfo::IsSpiAddress(address)) {
        device_info_.ISR_End(address, bytes);
      }
    }
  };
};


/// This is used on the auxiliary processor.  It exposes the following
/// functions:
///
/// A. A CAN bridge using an identical SPI mapping as the
/// CanApplication/CanBridge.
///
/// B. An IMU with the SPI mapping as per the Imu class.
///
/// C. A spread spectrum RF transceiver as per the RfTransceiver
/// class.
class AuxApplication {
 public:
  AuxApplication(mjlib::micro::Pool* pool, fw::MillisecondTimer* timer)
      : pool_(pool), timer_(timer) {
  }

  void Poll() {
    cpu_meter_.Poll();
    bridge_.Poll();
    imu_.Poll();
    rf_.Poll();
  }

  void PollMillisecond() {
    cpu_meter_.PollMillisecond();
    bridge_.PollMillisecond();
    spi_.PollMillisecond();
    imu_.PollMillisecond();
    rf_.PollMillisecond();
  }

 private:
  RegisterSPISlave::Buffer ISR_Start(uint16_t address) {
    if (CanBridge::IsSpiAddress(address)) {
      return bridge_.ISR_Start(address);
    }
    if (Imu::IsSpiAddress(address)) {
      return imu_.ISR_Start(address);
    }
    if (RfTransceiver::IsSpiAddress(address)) {
      return rf_.ISR_Start(address);
    }
    if (CpuMeter::IsSpiAddress(address)) {
      return cpu_meter_.ISR_Start(address);
    }
    if (address == 96) {
      // This is a multiplexing register which allows clients to
      // determine what is ready to read.
      read_buf_[0] = bridge_.queue_size();
      read_buf_[1] = imu_.data_present() ? 1 : 0;
      const auto bitfield = rf_.bitfield();
      std::memcpy(&read_buf_[2], &bitfield, sizeof(bitfield));
      return {
        std::string_view(&read_buf_[0], 6),
        {},
      };
    }
    if (DeviceInfo::IsSpiAddress(address)) {
      return device_info_.ISR_Start(address);
    }
    return {};
  }

  void ISR_End(uint16_t address, int bytes) {
    if (CanBridge::IsSpiAddress(address)) {
      bridge_.ISR_End(address, bytes);
    }
    if (Imu::IsSpiAddress(address)) {
      imu_.ISR_End(address, bytes);
    }
    if (RfTransceiver::IsSpiAddress(address)) {
      rf_.ISR_End(address, bytes);
    }
    if (DeviceInfo::IsSpiAddress(address)) {
      device_info_.ISR_End(address, bytes);
    }
    if (CpuMeter::IsSpiAddress(address)) {
      cpu_meter_.ISR_End(address, bytes);
    }
  }

  mjlib::micro::Pool* const pool_;
  MillisecondTimer* const timer_;

  fw::FDCan can1_{[]() {
      fw::FDCan::Options o;
      o.td = PA_12;
      o.rd = PA_11;
      o.slow_bitrate = 125000;
      o.fast_bitrate = 125000;
      o.fdcan_frame = false;
      o.bitrate_switch = false;
      o.automatic_retransmission = true;
      return o;
    }()
  };

  CpuMeter cpu_meter_;
  CanBridge bridge_{timer_, &can1_, nullptr, MakeCanPins()};

  DigitalOut can_shdn_{PC_6, 0};

  Imu imu_{pool_, timer_, PB_1};
  RfTransceiver rf_{timer_, PB_2};
  DeviceInfo device_info_;

  RegisterSPISlave spi_{
    timer_,
    MakeSpiPins(),
    [this](uint16_t address) {
      return this->ISR_Start(address);
    },
    [this](uint16_t address, int bytes) {
      this->ISR_End(address, bytes);
    }
  };

  char read_buf_[6] = {};
};

void SetupClock() {
  RCC_ClkInitTypeDef RCC_ClkInitStruct;

  RCC_ClkInitStruct.ClockType      = (RCC_CLOCKTYPE_SYSCLK | RCC_CLOCKTYPE_HCLK | RCC_CLOCKTYPE_PCLK1 | RCC_CLOCKTYPE_PCLK2);
  RCC_ClkInitStruct.SYSCLKSource = RCC_SYSCLKSOURCE_PLLCLK;
  RCC_ClkInitStruct.AHBCLKDivider = RCC_SYSCLK_DIV1; // 170 MHz
  RCC_ClkInitStruct.APB1CLKDivider = RCC_HCLK_DIV2;  //  85 MHz
  RCC_ClkInitStruct.APB2CLKDivider = RCC_HCLK_DIV2;  //  85 MHz

  if (HAL_RCC_ClockConfig(&RCC_ClkInitStruct, FLASH_LATENCY_6) != HAL_OK) {
    mbed_die();
  }

  {
    RCC_PeriphCLKInitTypeDef PeriphClkInit = {};

    PeriphClkInit.PeriphClockSelection = RCC_PERIPHCLK_FDCAN | RCC_PERIPHCLK_ADC345;
    PeriphClkInit.FdcanClockSelection = RCC_FDCANCLKSOURCE_PCLK1;
    PeriphClkInit.Adc345ClockSelection = RCC_ADC345CLKSOURCE_SYSCLK;
    if (HAL_RCCEx_PeriphCLKConfig(&PeriphClkInit) != HAL_OK) {
      mbed_die();
    }
  }
}

}
}

int main(void) {
  DigitalIn id_select1(PC_14);
  DigitalIn id_select2(PC_15);

  fw::SetupClock();

  mjlib::micro::SizedPool<20000> pool;
  fw::MillisecondTimer timer;

  auto run = [&](auto& app) {
    uint32_t last_ms = 0;
    while (true) {
      app.Poll();
      const auto now = timer.read_ms();
      if (now != last_ms) {
        app.PollMillisecond();
        last_ms = now;
      }
    }
  };

  // See what thing we're going to do.
  if (id_select1.read() == 1) {
    // We are the AUX processor.
    fw::AuxApplication application{&pool, &timer};

    run(application);
  } else {
    fw::CanApplication application{&timer};

    run(application);
  }
}

extern "C" {
void abort() {
  mbed_die();
}

void mbed_die(void) {
  // Flash an LED that exists.
  gpio_t led;
  gpio_init_out(&led, PF_1);

  for (;;) {
    gpio_write(&led, 0);
    wait_ms(200);
    gpio_write(&led, 1);
    wait_ms(200);
  }
}
}

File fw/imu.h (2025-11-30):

// Copyright 2023 mjbots Robotic Systems, LLC.  info@mjbots.com
//
// Licensed under the Apache License, Version 2.0 (the "License");
// you may not use this file except in compliance with the License.
// You may obtain a copy of the License at
//
//     http://www.apache.org/licenses/LICENSE-2.0
//
// Unless required by applicable law or agreed to in writing, software
// distributed under the License is distributed on an "AS IS" BASIS,
// WITHOUT WARRANTIES OR CONDITIONS OF ANY KIND, either express or implied.
// See the License for the specific language governing permissions and
// limitations under the License.

#pragma once

#include <atomic>
#include <cstdint>
#include <optional>
#include <string_view>

#include "mjlib/micro/pool_ptr.h"

#include "fw/attitude_reference.h"
#include "fw/bmi088.h"
#include "fw/icm42688.h"
#include "fw/millisecond_timer.h"
#include "fw/quaternion.h"
#include "fw/register_spi_slave.h"

namespace fw {

/// Exposes an IMU through the following SPI registers.
///
///  32: Protocol version:
///     byte 0: the constant value 0x20
///  33: Raw IMU data
///     bytes: The contents of the 'ImuRegister' structure
///  34: Attitude data
///     bytes: The contents of the 'AttitudeRegister' structure
///  35: Read configuration
///     bytes: The contents of the 'Configuration' structure
///  36: Write configuration
///     bytes: The contents of the 'Configuration' structure
///  37: Error status
///     byte 0-3: A bitmask of error flags
class Imu {
 public:
  struct ImuRegister {
    uint16_t present = 0;
    float gx_dps = 0;
    float gy_dps = 0;
    float gz_dps = 0;
    float ax_mps2 = 0;
    float ay_mps2 = 0;
    float az_mps2 = 0;

    ImuRegister() {}
    ImuRegister(const ImuData& data) {
      present = 1;
      gx_dps = data.rate_dps.x();
      gy_dps = data.rate_dps.y();
      gz_dps = data.rate_dps.z();
      ax_mps2 = data.accel_mps2.x();
      ay_mps2 = data.accel_mps2.y();
      az_mps2 = data.accel_mps2.z();
    }
  } __attribute__((packed));

  struct AttitudeRegister {
    uint8_t present = 0;
    uint8_t update_time_10us = 0;
    float w = 0;
    float x = 0;
    float y = 0;
    float z = 0;
    float x_dps = 0;
    float y_dps = 0;
    float z_dps = 0;
    float a_x_mps2 = 0;
    float a_y_mps2 = 0;
    float a_z_mps2 = 0;
    float bias_x_dps = 0;
    float bias_y_dps = 0;
    float bias_z_dps = 0;
    float uncertainty_w = 0;
    float uncertainty_x = 0;
    float uncertainty_y = 0;
    float uncertainty_z = 0;
    float uncertainty_bias_x_dps = 0;
    float uncertainty_bias_y_dps = 0;
    float uncertainty_bias_z_dps = 0;
    uint32_t error_count = 0;
    uint32_t last_error = 0;
  } __attribute__((packed));

  struct Configuration {
    float roll_deg = 0;
    float pitch_deg = 0;
    float yaw_deg = 0;
    uint32_t rate_hz = 400;

    Quaternion quaternion() {
      return Quaternion::FromEuler(
          Radians(roll_deg),
          Radians(pitch_deg),
          Radians(yaw_deg));
    }

    bool operator==(const Configuration& rhs) const {
      return yaw_deg == rhs.yaw_deg &&
          pitch_deg == rhs.pitch_deg &&
          roll_deg == rhs.roll_deg &&
          rate_hz == rhs.rate_hz;
    }

    bool operator!=(const Configuration& rhs) const {
      return !(*this == rhs);
    }
  } __attribute__((packed));

  Imu(mjlib::micro::Pool* pool, fw::MillisecondTimer* timer, PinName irq_name)
      : pool_(pool),
        timer_(timer),
        irq_(irq_name, 0) {
    // Detect if we have a BMI088/BMI090L or the ICM-42688-P
    ConfigureBmi088();
    if (bmi088_->setup_data().error) {
      bmi088_.reset();
      ConfigureIcm42688();
      if (icm42688_->setup_data().error) {
        // No IMU found!
        error_flags_ |= 1;
        return;
      }
    }
    attitude_reference_.emplace();

    // We do this here after everything has been initialized.
    next_imu_sample_ = timer_->read_us();

    setup_data_ = bmi088_->setup_data();
  }

  void Poll() {
    if (icm42688_) {
      // For the ICM-42688-P, we rely on its interrupt to tell us that
      // we should read data.
      if (icm42688_->data_ready()) {
        DoImu();
      }
    } else {
      // Otherwise we do it at a fixed interval.
      const auto now = timer_->read_us();
      if (now - next_imu_sample_ < 0x80000000) {
        // We have gone past.
        next_imu_sample_ += us_step_;
        DoImu();
      }
    }
  }

  void PollMillisecond() {}

  bool data_present() const {
    return imu_to_isr_.load() != nullptr;
  }

  static bool IsSpiAddress(uint16_t address) {
    return address >= 32 && address <= 37;
  }

  RegisterSPISlave::Buffer ISR_Start(uint16_t address) {
    if (address == 32) {
      return {
        std::string_view("\x20", 1),
        {},
      };
    }
    if (address == 33) {
      const int bit = 1;
      if (imu_isr_bitmask_ & bit) {
        ISR_GetImuData();
      }
      imu_isr_bitmask_ |= bit;
      if (imu_in_isr_) {
        return {
          std::string_view(reinterpret_cast<const char*>(&imu_in_isr_->imu),
                           sizeof(imu_in_isr_->imu)),
          {},
        };
      } else {
        return {{}, {}};
      }
    }
    if (address == 34) {
      const int bit = 2;
      if (imu_isr_bitmask_ & bit) {
        ISR_GetImuData();
      }
      imu_isr_bitmask_ |= bit;
      if (imu_in_isr_) {
        return {
          std::string_view(
              reinterpret_cast<const char*>(&imu_in_isr_->attitude),
              sizeof(imu_in_isr_->attitude)),
          {},
        };
      } else {
        return {{}, {}};
      }
    }
    if (address == 35) {
      return {
        std::string_view(
            reinterpret_cast<const char*>(&spi_config_),
            sizeof(spi_config_)),
        {},
      };
    }
    if (address == 36) {
      return {
        {},
        mjlib::base::string_span(
            reinterpret_cast<char*>(&spi_config_shadow_),
            sizeof(spi_config_shadow_)),
      };
    }
    if (address == 37) {
      return {
        {},
        mjlib::base::string_span(
            reinterpret_cast<char*>(&error_flags_),
            sizeof(error_flags_)),
      };
    }
    return {};
  }

  void ISR_End(uint16_t address, int bytes) {
    if (address == 36 &&
        bytes == sizeof(spi_config_shadow_)) {
      if (spi_config_ != spi_config_shadow_) {
        spi_config_ = spi_config_shadow_;
        // This is a data race, but we're about to throw away our entire
        // estimator, so who cares?
        mounting_ = spi_config_.quaternion();
        reset_estimator_.store(true);
      }
    }
  }

 private:
  void ConfigureBmi088() {
    bmi088_.emplace(timer_, [&]() {
        Bmi088::Options options;
        options.mosi = PB_15;
        options.miso = PB_14;
        options.sck = PB_13;
        options.acc_cs = PA_9;
        options.gyro_cs = PB_12;
        options.acc_int = PA_10;
        options.gyro_int = PA_8;
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

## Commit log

2019-05-30 Port all the hardware bits from https://github.com/mjbots/mjmech/tree/master/hw/pi3_hat
    [pi3_hat.brd, pi3_hat.sch]
2019-10-03 Beginnings of r4 with multiple FD-CAN busses
    [pi3_hat.brd, pi3_hat.sch]
2020-01-28 Fix up stm32 pinouts, add eeprom and test points
    [pi3_hat.brd, pi3_hat.sch]
2020-01-28 Rough place all components
    [pi3_hat.brd, pi3_hat.sch]
2020-01-29 Rough silks
    [pi3_hat.brd, pi3_hat.sch]
2020-01-29 Route power input
    [pi3_hat.brd, pi3_hat.sch]
2020-01-29 Route all power and place all test points
    [pi3_hat.brd]
2020-01-29 Fix enough things that the board with autoroute
    [pi3_hat.brd]
2020-01-29 More fiddling, and add a 3.3v test point
    [pi3_hat.brd, pi3_hat.sch]
2020-01-29 Select parts
    [pi3_hat.brd, pi3_hat.sch]
2020-01-29 Minor silk tweaks, re-autoroute with bottom layer up/down
    [pi3_hat.brd, pi3_hat.sch]
2020-01-29 Capture r4 as sent off
    [pi3_hat.brd, pi3_hat.sch]
2020-01-31 Fix R5/R6 to use parts that are the correct size
    [pi3_hat.brd, pi3_hat.sch]
2020-02-25 Basic SPI slave operation that works at least a little
    [pi3_hat.brd, pi3_hat.sch]
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2020-02-26 If FDCAN is out of space, keep trying to send
    Also, don't always abort old frames when enqueuing new ones
2020-02-29 Add mjbots logo
    [pi3_hat.brd, pi3_hat.sch]
2020-02-29 Add debug pads for each processor
    [pi3_hat.brd, pi3_hat.sch]
2020-02-29 Don't die if we can't get a packet out
    But this still doesn't do anything useful. Also, when mbed_die is
    called, flash a light which actually exists.
    [pi3_hat.cc]
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2020-03-03 Expose the IMU data in a way that lets a client get everything
2020-03-04 Report the time spent doing IMU work
    Switch to a newer rules_mbed that lets us optimize for speed instead
    of size. This makes a big difference with Eigen, going from 1000us to
    around 260us for the IMU calculation.
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2020-03-04 Implement a constraint on the yaw bias and tune constants a bit
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2020-03-05 Improve SPI performance
    We were occasionally dropping some bytes while interrupts were
    disabled. Stop disabling interrupts, and instead use a more
    complicated scheme to exchange data with the ISR that relies on atomic
    exchanges.
    While we're at it, improve the overall latency of the primary SPI isr
    to give us even more margin.
2020-03-22 Switch the aux CAN to the LTC2875
    [pi3_hat.brd, pi3_hat.sch]
2020-03-22 Flip rpi header start populating it, stop populating NRF header
    [pi3_hat.brd, pi3_hat.sch]
2020-03-22 Add IRQ lines to the rpi
    [pi3_hat.brd, pi3_hat.sch]
2020-03-22 Expose debug pins on 0.1" headers, give 4 debug pins on the aux processor
    [pi3_hat.brd, pi3_hat.sch]
2020-03-22 Stick two rpi pins on a header and fix silks
    [pi3_hat.brd, pi3_hat.sch]
2020-03-22 Add microphone to aux processor
    [pi3_hat.brd, pi3_hat.sch]
2020-03-22 Flip NRF around, add an LC filter and a ground plane
    [pi3_hat.brd, pi3_hat.sch]
2020-03-22 Fine tweak silks
    [pi3_hat.brd]
2020-03-22 Update board rev to 4.1, since we haven't made one of those yet
    [pi3_hat.brd, pi3_hat.sch]
2020-03-22 Add MPN for LTC2875
    [pi3_hat.brd, pi3_hat.sch]
2020-03-22 Tweak another silk
    [pi3_hat.brd]
2020-03-23 r4.1 as sent for mfg
    [pi3_hat.brd, pi3_hat.sch]
2020-03-27 Stop relying on the bmi088 gyro interrupt to advance time
    It turns out, it isn't a reliable indicate of when data is available,
    since there is no way to clear it. Instead, just sample at the appropriate fixed frequency.
    [bmi088.cc, pi3_hat.cc]
2020-03-27 Use the correct coordinate conventions
    [attitude_reference.h]
2020-03-28 Update quaternion to use the current coordinate conventions
    +x is forward
    +y is right
    +z is down
2020-03-28 Split out the IMU into a separate class
    Further, we put the Eigen heavy stuff in a cc file so that we don't
    have to wait 60s for every compile of everything.
2020-04-23 Add some stls to hold the RF module
    [rf_clamp.3mf, rf_clamp.stl, rf_support.3mf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]
2020-04-23 Checkpoint of stub microphone code
    This doesn't work yet, the ADC always reads a very small value and it
    doesn't look like the opamp is properly biasing the input yet.
    [pi3_hat.cc]
2020-04-23 Tweak enough to get the mic working
    Notably, the sound quality is terrible, plus only sampled at 1kHz so
    makes it even worse.
2020-04-23 Switch capacitors and shift the NRF header a bit further up
    [pi3_hat.brd, pi3_hat.sch]
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2020-06-09 A new bracket to support a random RF board
    [rf_support_and_clamp.3mf]
2020-06-10 Rework the SPI protocol and CAN protocol, provide client library
    This tries to make the CAN protocol more byte efficient over the SPI
    bus, dropping 4 bytes per write transaction and 2 bytes per read
    transaction. The 16 bit address is decreased to 8, the top two bytes
    of the CAN ID can be omitted, and the size and can bus are stuck into
    one byte.
    The new client library doesn't support RF control yet, but has
    otherwise been minimally tested against CAN and IMU for both primary
    and aux processors.
    [can_bridge.h, pi3_hat.cc]
2020-06-10 Get RF control working
    This updates the Nrf24l01 and SlotRfProtocol class from nrfusb. It
    also makes a fix to disable interrupts while re-configuring the
    SlotRfProtocol, as we expect to be able to access it from interrupt
    context.
    [nrf24l01.cc, nrf24l01.h, pi3_hat.cc]
2020-06-10 Refactor so CanBridge no longer owns the RegisterSpiSlave
    This probably makes things slightly faster and simpler to reason
    about.
    [can_bridge.h, imu.h, pi3_hat.cc]
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2020-06-10 Instead of asserting on NaN, report an error and reset
    [attitude_reference.h, imu.h]
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2020-06-15 Fix a comment typo
    [can_bridge.h]
2020-06-15 Add an updated RF support and clamp
    [rf_clamp.stl, rf_support.stl]
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2020-10-01 Add a mechanical solid model
    [pi3hat_r4_1.step]
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2020-11-13 Automatically recover from can Bus_Off state
    The documentation on how to do this is basically non-existent, as is
    anything in Google as of 2020-11-13. Older versions of the ST CAN
    peripheral had a mechanism to automatically recover from Bus_Off, but
    no more. It seems that just asking the peripheral to re-initialize by
    clearing INIT in CCCR is sufficient to get it working, so we'll go
    with that. That is hinted at by the italicized note in '43.4.13 FDCAN
    protocol status register (FDCAN_PSR)' of the reference manual.
    While we are at it, expose some CAN error information over SPI.
    [can_bridge.h, fdcan.cc, fdcan.h]
2020-11-17 Capture r4.2
    [pi3_hat.brd, pi3_hat.sch]
2020-11-17 Draft of a r4.3 board
    [pi3_hat.brd, pi3_hat.sch]
2020-11-17 Tweak placements
    [pi3_hat.brd]
2020-11-17 More tweaking placement
    [pi3_hat.brd]
2020-11-17 Yet more silk tweaks
    [pi3_hat.brd]
2020-11-17 Tweak JP6 to line up with JP1
    [pi3_hat.brd]
2020-11-17 Normalize JP6 silk size
    [pi3_hat.brd]
2020-11-17 r4.3 as sent to osh
    [pi3_hat.brd, pi3_hat.sch]
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2020-12-15 libpi3hat: Check for the hat version string
    If there is no actual pi3hat present, this causes us to fail before we
    spam the SPI busses trying to talk to one.
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2020-12-18 Rev hw to r4.4 * Move C1 silk to not be on a pad * Use a fuse rated for the new input voltage
    [pi3_hat.brd, pi3_hat.sch]
2020-12-29 Switch to using a SMT 40 pin connector that mates from either side
    There are still a lot of airwires left here
    [pi3_hat.brd, pi3_hat.sch]
2020-12-29 Finish routing and silk placement for r4.4
    [pi3_hat.brd]
2020-12-29 Include correct new part number for EEPROM
    [pi3_hat.brd, pi3_hat.sch]
2020-12-30 Oops, still had two components on the back side
    [pi3_hat.brd]
2020-12-30 Fine place silks
    [pi3_hat.brd]
2020-12-30 A bit more silk fine place
    [pi3_hat.brd]
2021-01-01 Decouple the pi3hat version from moteus and fix non-config case
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2021-01-08 r4.4 as sent for mf
    [pi3_hat.brd, pi3_hat.sch]
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2021-02-09 Make a 4.4b that uses the old through hole rpi connector
    [pi3_hat.brd, pi3_hat.sch]
2021-02-10 Add an optional ICM-42688-P in parallel to the BMI088/BMI090L
    It seems to have better availability and specs. This way either can
    be populated on the board depending upon what I can get.
    [pi3_hat.brd, pi3_hat.sch]
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2021-02-14 Capture 4.4b
    [pi3_hat.brd, pi3_hat.sch]
2021-02-14 Properly document the order of ypr in IMU mounting config
    The C++ library has been updated to use the correct names. This will
    break any existing C++ clients which were relying on the previous swap
    of yaw and roll.
    [imu.h]
2021-04-11 Update name of 4.4b
    [pi3_hat.brd, pi3_hat.sch]
2021-04-12 Preliminary support for ICM-42688 on the r4.4b
    This seemingly works on both r4.4 and r4.4b, although no real
    qualification has been done on the ICM-42688 yet aside from verifying
    the signs are correct.
    [bmi088.cc, icm42688.cc, imu.h]
2021-04-12 Remove microphone support
    New boards don't have it, and old boards didn't use it
    [pi3_hat.cc]
2021-04-12 Clock the ICM-42688-P from the stm32
    To ensure we don't drop any samples, use the ICM-42688-P's IRQ to
    decide when to read things, instead of just doing so on a fixed cycle.
    [icm42688.cc, imu.h]
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2021-04-29 Fix a typo in a comment
    [can_bridge.h]
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2021-09-10 Make slow SPI speeds work on the auxiliary SPI master
    The auxiliary SPI driver could get desynchronized with the hardware
    when reading using low bit rates. It was only looking to see if the
    TX queue was empty, which doesn't actually tell you if the hardware is
    done doing stuff or not.
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2021-11-29 And report to SPI the correct auto-retransmit flag as well
    [can_bridge.h]
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2022-06-06 Fix the docs for the attitude data SPI register
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2022-06-16 Increase the setup and hold times
    On aarch64, the kernel does something funny with the times returned
    from clock_gettime. I had to increase the times to 9us to avoid
    sometimes having an actual delay of less than a microsecond.
    The "official" way to do this is nanosleep, which has a minimum sleep
    time of more like 20us. I guess the next step would be to calibrate
    some bogomips and use that.
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2023-01-25 pi3hat r4.5
    * Up voltage rating to 48V (technically 10V-54V)
    * Replace CAN transceivers with 5V versions (with DNPs to support 3.3V
    ones if necessary)
    * Use actual 120 ohm terminating resistors
    * 0.1" I2C header
    [pi3_hat.brd, pi3_hat.sch]
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2023-05-23 pi3hat r4.5b * slightly tweak the position of R14 to improve clearance
    [pi3_hat.brd, pi3_hat.sch]
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2023-08-22 Update to a new timeout scheme for increased robustness
    This makes a few changes:
    * Now, before every cycle, we first try to clear out any stale
    responses that are left in the pi3hat. If we had a previous
    timeout, this will help stop us from getting into an out-of-phase
    situation.
    * Treat bus 5 like any other, since it is equivalent on modern boards.
    * Add a parallel timeout calculation based on how long we expect to
    need before a reply will be received. This timeout will only happen
    if no expected replies are received. By default set this long, and
    leave the required minimum time shorter. This should decrease the
    typical cycle time, while being even more robust, especiall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
2025-09-08 If no CAN frames are making it out, just discard
    Otherwise, the MCU ends up busy looping, preventing any other
    functions from actually working.
    [can_bridge.h]
2025-09-18 Be more robust when no device acknowledges a frame
    If the pi3hat attempts to send a CAN frame and no device acknowledges
    it, the retranmissions continue indefinitely. If the host keeps
    enqueueing packets, eventually the hardware FIFO becomes full. At
    that point, the firmware would enter a busy loop preventing anything
    further from working.
    We resolve that in two ways.
    First, if the hardware FIFO is full, just discard new frames sent from
    the host.
    Second, 50ms after the last frame was successfully enqueued with the
    hardware, cancel all outstanding transmissions. This ensures that a
    single frame which is never acknowledged by anything does not prevent
    later frames with an address that w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
    [can_bridge.h, fdcan.cc, fdcan.h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]
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2025-09-18 Fix some cancellation safety issues
    First, require that each _transaction not be cancelled. Using the
    pi3hat cpp interface, we don't expect any individual call to take very
    long anyway as we have pretty tight timeouts.
    Second, if a subscription handler is cancelled but a frame is received
    anyway, stick it in the global queue so that it isn't lost.
    Exception safety is hard.
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2026-09-04 cpp: Guard against malformed short CAN frames in ReadCanFrames
    A queue-size byte of 1..4 (with a nonzero flags byte) would make the
    `memcpy` length `size - 5` a negative int, resulting in UB. This
    could happen because of a SPI bit error. Be defensive and avoid UB.
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2026-09-04 Migrate firmware and host CC toolchains to platform resolution
    The previous commit moved the Raspberry Pi cross-compiles to Bazel's
    platform-based toolchain resolution. Finish the job for the rest of the
    build: enable cc-toolchain-resolution globally, select the firmware
    (stm32g4 / rules_mbed) toolchain via --platforms, add a host
    configuration that uses the autodetected local toolchain, and drop the
    now-redundant per-config --incompatible_enable_cc_toolchain_resolution
    flags and the last --crosstool_top.
    --cpu is kept only for output-directory naming and the
    //:python*_{armeabihf,aarch64} config_settings.
2026-09-04 cpp: Update the stale CanFrame::bus speed documentation
    The high speed (JC1-JC4) vs low speed (JC5) distinction only applied
    to boards older than r4.5; modern boards make no distinction. Also
    fix the spelling of pi3hat in the class comment.
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2026-09-04 cpp: Validate servo-map buses and reject conflicting duplicates
    ParseServoMap accepted any bus number (a typo'd bus silently
    misrouted, since CHILD_FindBus returns whatever the map holds) and
    silently kept the first mapping when a servo id appeared on two
    buses. Report both as errors; a repeated identical mapping remains
    accepted.
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

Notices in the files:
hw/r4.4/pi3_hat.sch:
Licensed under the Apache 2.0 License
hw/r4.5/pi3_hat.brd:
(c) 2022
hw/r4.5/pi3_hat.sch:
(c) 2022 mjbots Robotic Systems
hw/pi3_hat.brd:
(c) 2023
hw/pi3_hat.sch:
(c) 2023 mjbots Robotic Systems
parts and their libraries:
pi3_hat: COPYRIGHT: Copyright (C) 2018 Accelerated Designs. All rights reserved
